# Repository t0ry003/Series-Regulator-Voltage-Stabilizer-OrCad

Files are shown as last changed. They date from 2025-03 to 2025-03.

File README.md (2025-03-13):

# Series Regulator Voltage Stabilizer (ERS)

## Overview
This project is a **Series Regulator Voltage Stabilizer (ERS)** designed to maintain a stable output voltage despite variations in input voltage and load conditions. The system leverages **error amplifiers, negative feedback loops, and protective circuits** to ensure high precision, efficiency, and reliability.

Developed as part of an academic project at the **Polytechnic University of Bucharest - Faculty of Electronics, Telecommunications, and Information Technology**, this stabilizer serves as a practical implementation of **linear voltage regulation**.

## Features
- **Precise Voltage Regulation**: Maintains a stable output voltage using an operational amplifier-based error correction system.
- **Negative Feedback Control**: Ensures accuracy by continuously comparing output voltage with a reference voltage.
- **Thermal Protection**: Automatic shutdown in case of overheating to prevent component damage.
- **Current Limiting**: Prevents excessive current draw, protecting the circuit and connected devices.
- **High Efficiency**: Optimized component selection to minimize power dissipation and improve thermal performance.

## System Design
The stabilizer consists of the following key elements:
1. **Error Amplifier**: Uses an operational amplifier in a non-inverting configuration to compare the output voltage with a reference.
2. **Voltage Reference Generator**: A Zener diode-based system provides a stable reference voltage.
3. **Series Regulating Element (ERS)**: Implements a **Darlington transistor configuration** to control the output voltage.
4. **Protection Mechanisms**:
   - **Overcurrent Protection**: Detects excessive load currents and limits output.
   - **Overtemperature Protection**: Monitors and prevents overheating of key components.

## Schematic Diagram
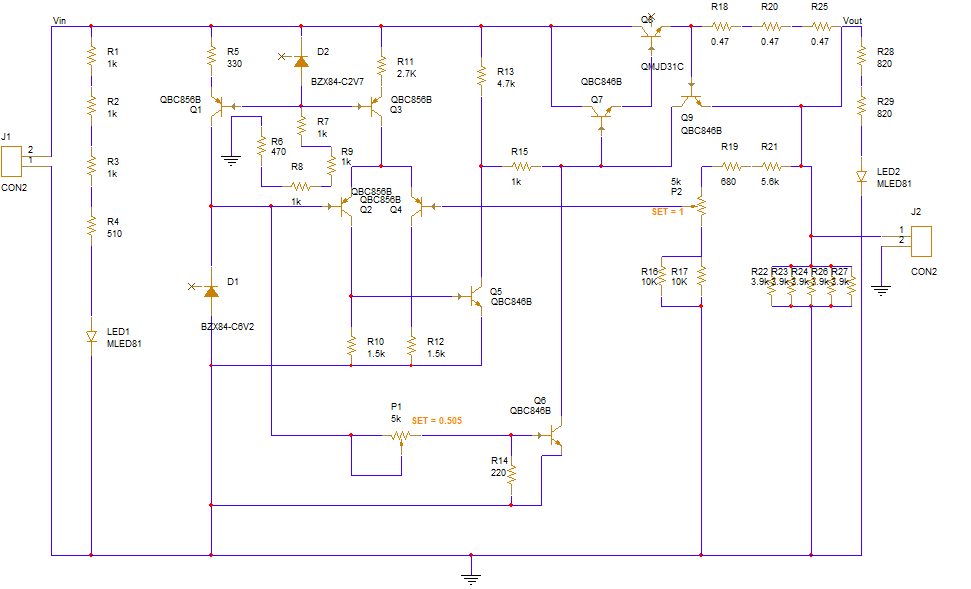
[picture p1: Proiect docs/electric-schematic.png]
Schematic Design


## PCB Design
This project includes a **fully designed PCB layout**, which can be fabricated for practical testing and implementation.
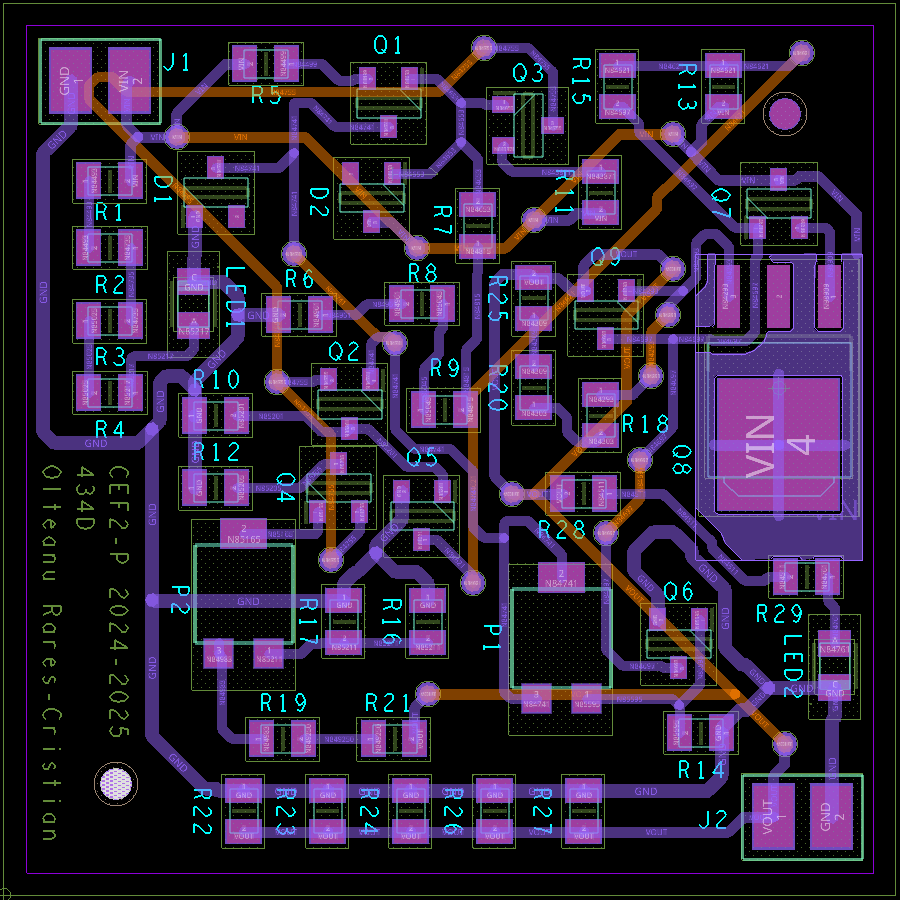
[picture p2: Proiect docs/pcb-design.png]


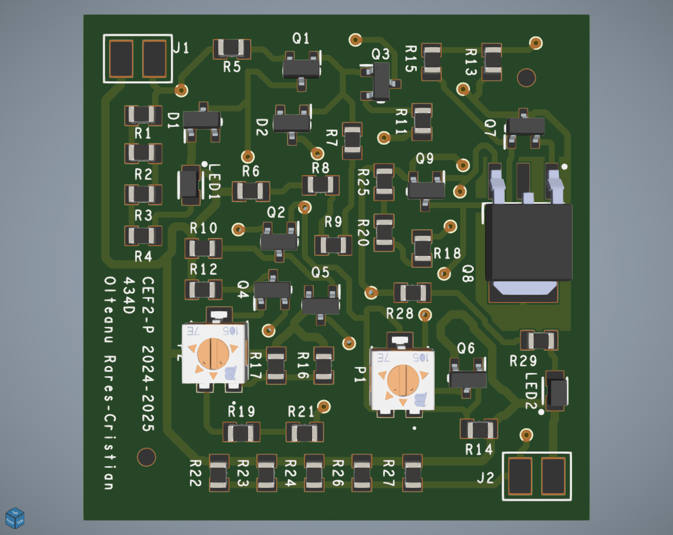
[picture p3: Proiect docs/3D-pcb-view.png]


## Simulations & Testing
Multiple simulations have been conducted to verify:
- **Output voltage stability across different input voltages (36V-40V)**
- **Response to load variations**
- **Thermal response and efficiency**
- **Gain characteristics of the error amplifier**

## How to Use
1. **Power Input**: Connect a **36V-40V DC** power source to the input terminals.
2. **Adjust Output Voltage**: Fine-tune using the onboard potentiometer (adjustable from **10V to 20V**).
3. **Monitor Performance**: Use an oscilloscope or multimeter to verify the output voltage and ensure stable operation.
4. **Safety Measures**: Ensure adequate heat dissipation and do not exceed the rated current limits.

## Bill of Materials (BOM)
| Qty | Ref | Part Number |
|-----|-----|---|
| 1 | D1  | BZX84-C6V2 |
| 1 | D2  | BZX84-C2V7 |
| 2 | J1, J2 | CON2 |
| 2 | LED1, LED2 | MLED81 |
| 2 | P1, P2 | 5k |
| 4 | Q1, Q2, Q3, Q4 | QBC856B |
| 4 | Q5, Q6, Q7, Q9 | QBC846B |
| 1 | Q8  | QMJD31C |
| 7 | R1, R2, R3, R7, R8, R9, R15 | 1k |
| 1 | R4  | 510 |
| 1 | R5  | 330 |
| 1 | R6  | 470 |
| 2 | R10, R12 | 1.5k |
| 1 | R11 | 2.7K |
| 1 | R13 | 4.7k |
| 1 | R14 | 220 |
| 2 | R16, R17 | 10K |
| 3 | R18, R20, R25 | 0.47 |
| 1 | R19 | 680 |
| 1 | R21 | 5.6k |
| 5 | R22, R23, R24, R26, R27 | 3.9k |
| 2 | R28, R29 | 820 |

## Applications
- **Power supply modules** requiring stable voltage regulation;
- **Embedded systems** where voltage precision is crucial;

## License
This project is open-source and can be used or modified under the **MIT License**.

## Contact & Credits
Developed by: **Olteanu Rareș Cristian**  
Institution: **Polytechnic University of Bucharest**  
Supervisor: **Drăghici Florin**

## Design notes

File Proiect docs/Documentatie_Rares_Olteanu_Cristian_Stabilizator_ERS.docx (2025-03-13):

# Proiect Dispozitive și Circuite Electronice

Olteanu Rareș Cristian

Grupa: 434D

Stabilizator de tensiune cu element regulator serie

Universitatea Politehnica din Bucureşti - Facultatea de Electronică şi Telecomunicaţii

Prof. Coordonator: Drăghici Florin

# 1. Stabilizatoarele de tensiune cu element de reglaj serie (ERS)

Stabilizatoarele de tensiune cu element de reglaj serie, care utilizează amplificatoare de eroare, sunt sisteme complexe, proiectate pentru a menține o tensiune constantă la ieșire în ciuda variațiilor de sarcină sau tensiune de intrare. Aceste stabilizatoare funcționează conform principiului reacției negative și sunt frecvent utilizate datorită preciziei și fiabilității lor.

## 1.1. Configurația generală a stabilizatoarelor cu amplificator operațional

Aceste stabilizatoare folosesc amplificatoare operaționale (AO) ca amplificatoare de eroare în configurație neinversoare. În această configurație avem:

1. Intrarea neinversoare primește o tensiune de referință (denumită Vref), generată de obicei de un stabilizator parametric, cum ar fi unul cu diodă Zener.

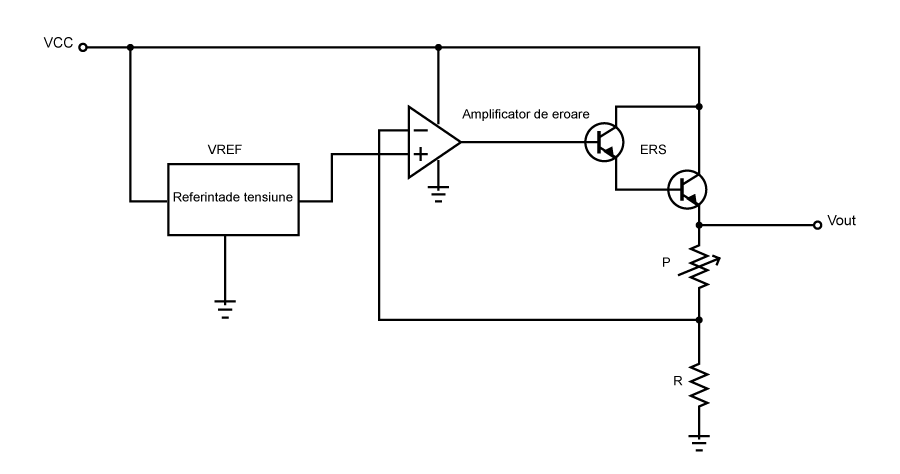
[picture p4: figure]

2. Intrarea inversoare primește o fracțiune din tensiunea de ieșire, preluată printr-un divizor de tensiune. Divizorul este format din rezistențe care ajustează nivelul semnalului proporțional cu tensiunea de ieșire.

(Fig. 1) Schema bloc a stabilizatorului de tensiune cu ERS

## 1.2. Funcționarea amplificatorului operațional

Amplificatorul operațional are un factor de amplificare foarte mare în buclă deschisă. Acest lucru determină ca diferența de potențial între intrările inversoare și neinversoare să fie extrem de mică în timpul funcționării normale. Prin urmare, orice modificare a tensiunii de ieșire care creează o diferență între aceste două intrări va genera o tensiune diferențială la ieșirea AO. Această tensiune va fi folosită pentru a corecta variația prin comanda elementului de reglaj serie, restabilind echilibrul.

## 1.3. Principiul funcționării

Stabilizatoarele liniare de tensiune continuă (SLTC) se bazează pe:

- Conexiunea cu reacție negativă, care monitorizează și ajustează continuu tensiunea de ieșire (P – potențiometrul si R – rezistenta, Fig. 1)
- Comparația între tensiunea de ieșire și tensiunea de referință, realizată de amplificatorul de eroare.

## 1.4. Indicatori de performanță ai stabilizatoarelor liniare

Calitatea unui stabilizator este determinată de mai mulți parametri esențiali:

1. Coeficientul de stabilizare (S0) - reprezintă capacitatea stabilizatorului de a menține tensiunea constantă în fața variațiilor de intrare. Valori mai mari indică o performanță superioară.
2. Rezistența de ieșire (R0) - influențează cât de mult scade tensiunea la ieșire pe măsură ce crește curentul de sarcină. Rezistența scăzută este dorită pentru o stabilitate mai bună.
3. Coeficientul de temperatură (KT) - exprimă sensibilitatea stabilizatorului la variațiile de temperatură. O valoare mică asigură o performanță constantă în condiții de mediu diferite.

## 1.5. Protecții integrate în stabilizatoare

Pentru a preveni deteriorarea circuitului în condiții de suprasarcină sau scurtcircuit, majoritatea stabilizatoarelor liniare moderne includ:

- Circuite de limitare a curentului de ieșire, care previn suprasolicitarea regulatorului serie. Această limitare poate fi:
1. Simplă, protejând doar împotriva curentului excesiv.
2. Cu întoarcerea curentului, unde, în cazul unui scurtcircuit, se reduce și puterea disipată de regulator.

## 1.6. Structura amplificatorului de eroare

S-a utilizat o configurație de amplificator operațional neinversor, în care factorul de amplificare în tensiune (Av) este determinat de relația matematică:

A_ν =1+(R_2)/(R_1)

Pentru implementarea amplificatorului de eroare, s-a adoptat o arhitectură clasică de amplificator operațional în clasa A, care este structurată în două secțiuni principale:

1. Secțiunea de intrare și semnal mic, responsabilă pentru adaptarea impedanțelor și procesarea semnalului de mică amplitudine.
2. Secțiunea de amplificare în tensiune, care realizează o amplificare semnificativă a semnalului.

Această divizare permite utilizarea etajelor specializate fie pentru amplificare în curent, fie pentru amplificare în tensiune, optimizând astfel performanța generală a circuitului.

### 1.6.1. Etajele amplificatorului

#### a) Etajul de intrare

Etajul de intrare este configurat ca amplificator diferențial, având rolul principal de a asigura adaptarea impedanței între sursa de semnal (impedanță mare) și etajele ulterioare (impedanță mică). Acesta funcționează conform principiului de transconductanță, transformând semnalul de intrare de tip tensiune într-un semnal de tip curent.

#### b) Etajul de amplificare în tensiune

Al doilea etaj, dedicat amplificării semnalului, este de tip trans impedanță și transformă curentul provenit de la etajul de intrare într-un semnal de tensiune de amplitudine mare. Amplificarea în tensiune a acestui etaj este extrem de mare în regim de buclă deschisă. Pentru a asigura o funcționare stabilă și o amplificare utilă, se implementează obligatoriu o buclă de reacție negativă, care reduce amplificarea totală la o valoare controlată.

### 1.6.2. Caracteristici funcționale ale etajelor amplificatorului

Etajele amplificatorului sunt conectate în cascadă, ceea ce determină înmulțirea factorilor de amplificare individuali. Cu toate acestea, etajul pilot contribuie majoritar la amplificarea totală în tensiune a amplificatorului.

## 1.7. Componente adiționale

Pe lângă etajele de amplificare, circuitul este completat de următoarele componente:

- Circuite de protecție, care asigură fiabilitatea în condiții de funcționare anormală (suprasarcină, temperatură, etc.).
- Generator de tensiune de referință, care furnizează un semnal stabil utilizat ca punct de comparație pentru amplificatorul de eroare.
- Rețea de reacție, utilizată pentru controlul precis al tensiunii de ieșire prin ajustarea amplificării și stabilității circuitului.

Această arhitectură permite obținerea unei amplificări eficiente, cu performanțe stabile și adaptabile diverselor aplicații.

# 2. Funcționarea schemei

(Fig. 2) Schema circuit stabilizator de tensiune cu ERS

(Fig. 3) Tensiunea de referința si amplificatorul de eroare diferențial

Proiectul a fost realizat pentru N = 20

## 2.1. Referința de tensiune

Referința de tensiune este generată cu ajutorul unei diodă Zener (D2), alimentată printr-un curent constant asigurat de tranzistorul Q1 și rezistența R2. Alegerea diodei Zener se face astfel încât tensiunea sa nominală (VZ) să fie mai mică decât tensiunea minimă ce trebuie obținută la ieșire (Vmin). În acest caz, s-a optat pentru o diodă Zener cu VZ = 6.2V. (Fig. 3)

Curentul constant prin dioda Zener D2 este generat de tranzistorul Q1, care formează o sursă de curent constant. Aceasta asigură o tensiune de referință stabilă pentru funcționarea optimă a schemei.

## 2.2. Etajul diferențial

Elementul central al schemei este amplificatorul diferențial, realizat cu tranzistoarele Q3 și Q4. Acesta este alimentat printr-o sursă de curent constant, formată din tranzistorul Q2 și rezistența R4. (Fig. 3)

Rolul acestui etaj este de a realiza atât amplificarea în tensiune, cât și amplificarea în curent. Pentru îndeplinirea acestor sarcini se folosesc etaje specializate:

- Etajul de intrare facilitează adaptarea între sursa de semnal și amplificator.
- În plus, contribuie la eliminarea fluctuațiilor provenite de la sursa de alimentare, având un impact direct asupra raportului semnal-zgomot.

## 2.3. Stabilizarea tensiunii

Pentru a îmbunătăți stabilitatea circuitului, o diodă D1 este utilizată pentru a menține tensiunea constantă pe sursele de curent constant. Aceasta fixează tensiunea pe rezistențele R2 și R4, ceea ce contribuie la stabilizarea generală a circuitului. (Fig. 3)

Astfel, integrarea diodei D1 reduce variațiile nedorite, îmbunătățind performanțele sursei de alimentare și menținând parametrii tensiunii de ieșire în limite stricte.

La pornire, joncțiunea bază-emitor (BE) a tranzistorului Q1 intră în conducție prin intermediul rezistorului R1. Curentul furnizat de această sursă poate fi calculat utilizând formula:

I_(C_1) =(v_z -v_(BE))/(R_2)

I_(C_1) =6mA

Curentul prin etajul diferențial este stabilit de rezistența R4, având la borne o tensiune de aproximativ:

v_z -v_(BE)

Astfel, curentul IC2 este calculat ca:

I_(C2) =0.8mA

Cum curentul colector al tranzistoarelor Q3 și Q4 este împărțit egal:

Ic_3 +I_(C4) =(Ic_2)/2 → Ic_3 =I_(C4) =0.4mA

Rezistențele R5 și R6 furnizează curentul de polarizare pentru etajul următor. Rezistorul R5 este dimensionat astfel încât să asigure o cădere de tensiune minimă de 0.6V, necesară pentru a aduce în conducție tranzistorul Q5.

### 2.3.1. Componentele utilizate

- Etajul diferențial este realizat cu tranzistoare bipolare PNP de tipul BC856.
- Etajul de emitor comun utilizează un tranzistor NPN de tipul BC846.

Aceste tranzistoare sunt adecvate, deoarece:

- Tensiunea de alimentare a circuitului este de 40V.
- Curentul colector pentru fiecare tranzistor diferențial Q3 și Q4 este limitat la 0.4mA.

### 2.3.2. Etajul amplificator în tensiune

Etajul de amplificare în tensiune este format dintr-un singur tranzistor bipolar Q5, configurat ca emitor comun. Sarcina acestui etaj este rezistorul R7.

Curentul prin R7 poate fi determinat cunoscând că tensiunea la bornele acestuia este aproape întotdeauna egală cu:

V_(CC) - V_(OUT) +2V_(BE)

Această configurație asigură funcționarea stabilă și precisă a circuitului.

Curentul IC5 este egal cu curentul IR7, iar relația acestuia poate fi exprimată astfel:

I_(C5) =I_(R7) =(V_(CC) -V_(OUT) +2V_(BE))/(R_7)

Amplificarea în tensiune a etajului emitor comun depinde de rezistența internă de emitor și de rezistența văzută în colector (adică a sursei de curent). Aceasta se poate calcula folosind formula:

A_(V5) =(R_7)/(R_(E5))

Unde R_(E5) =(V_T)/(I_C) , rezulta R_(E5) =(25mV)/(4mA)≅6Ω

R_7 =4.7kΩ , rezulta A_(V5) ≅780

(Fig. 4) Elementul regulator serie

## 2.4. Elementul regulator serie (ERS)

Elementul regulator serie este realizat pe baza unei conexiuni de colector comun. Acest tip de etaj oferă doar amplificare în curent și este numit și etaj final, deoarece asigură adaptarea către impedanța sarcinii. Scopul acestui etaj este să amplifice în curent, menținând în același timp o amplificare unitară în tensiune.

Pentru a asigura condiția de amplificare unitară în tensiune, vom utiliza o conexiune de tip colector comun realizată cu două tranzistoare bipolare în configurație Darlington (Q6 si Q7). Această configurație oferă cea mai mare amplificare în curent posibilă. Factorii de amplificare ai celor două tranzistoare se înmulțesc, rezultând o amplificare în curent de ordinul 10⁴. (Fig. 4)

Tranzistorul final este Q7, care conduce cea mai mare parte a curentului. Din acest motiv, a fost ales modelul MJD31, deoarece poate suporta curenți de până la 3A și poate disipa o putere mai mare decât alte modele de tranzistoare (pana la 25W, comparat cu altele care suporta pana la 250mW).

(Fig. 5) Circuitul de protecție la supracurent

## 2.5. Circuitul de protecție la supracurent

Circuitul de protecție la supracurent Q9 + R10 + R11 + R12 este realizat cu un tranzistor bipolar NPN. Tensiunea VBE a tranzistorului este generată de căderea de tensiune pe aceste rezistoare. Astfel, la curenți mari (>0.5A), tranzistorul Q9 va intra în conducție și va limita curentul de bază al regulatorului serie.

Pentru a obține o valoare precisă de 1.4 Ω, au fost utilizate trei rezistoare în serie.

Dimensionarea rezistorului se face conform relației:

R=(V_(BE))/(I_(OMAX))

R = R10 + R11 + R12

Astfel, pentru un curent maxim de 0.5 A, rezultă o valoare de aproximativ 1.4 Ω pentru R.

(Fig. 6) Circuitul de protecție la temperatură

## 2.6. Circuitul de protecție la temperatură

Circuitul de protecție la temperatură este realizat cu Q8 și un divizor rezistiv format din P2 și R8.

Tensiunea bază-emitor pentru Q8 este stabilită de divizor la un nivel care împiedică intrarea în conducție a tranzistorului Q8 (aproximativ 400 mV). Totuși, la temperaturi ridicate, datorită coeficientului termic negativ al joncțiunilor din siliciu (−2 mV/°C), potențialul stabilit de divizor devine suficient de mare pentru ca Q8 să intre în conducție.

Astfel, la temperaturi de peste 120°C, se limitează curentul de bază al regulatorului serie, iar tensiunea de la ieșire scade către 0.

Potențialul VBE este stabilit la aproximativ 400 mV conform raportului dintre P2 și R8, după relația:

V_(BE8) =V_(ref) ×(P_2)/(R_8 +P_2) , unde V_(ref) =6.2V

Din potențiometrul P2 se reglează cu precizie valoarea temperaturii la care acționează protecția. In acest caz a fost reglat la 0.505 (2,525kΩ)

(Fig. 7) Rețeaua de reacție negativă

## 2.7. Rețeaua de reacție negativă

Rețeaua de reacție negativă este formata din potențiometrul P1 si doua grupuri de rezistente: R14, R15 si R16, R17 . Acestea realizează un divizor de tensiune variabil din potențiometru care are ca scop reglarea tensiunii de ieșire.

Știm că V_(out min) =10V, V_(out max) =20V, V_(ref) =6.2V

R=6.2/10=0.62kΩ

V_(ref) =V_(out min) ×(P_1 +R_16 ∥R_17)/(P_1 +R_16 ∥R_17 +R_14 +R_15)=10V×10/(10+6.28)kΩ=6.14V

R=6.2/20=0.31kΩ

V_(ref) =V_(out min) ×(R_16 ∥R_17)/(P_1 +R_16 ∥R_17 +R_14 +R_15)=10V×5/(10+6.28)kΩ=6.14V

Din aceste relații, am ales valorile:

R_14 =0.6kΩ, R_15 =5.6kΩ, R_16 =R_17 =10kΩ (R_16 ∥R_17 =5kΩ), P_1 =5kΩ

# 3. Punct static de funcționare (simulari)

(Fig. 8) Punct static de funcționare – afișare tensiuni

(Fig. 9) Punct static de funcționare – afișare curenți

(Fig. 10) Punct static de funcționare – afișare puteri disipate

Se poate observa alegerea corecta a componentelor electrice si folosirea lor corespunzătoare. Au fost respectate toate cerințele impuse de producător, ba chiar la majoritatea a fost lăsata o marjă pentru siguranță.

# 4. Simulări funcționalitate

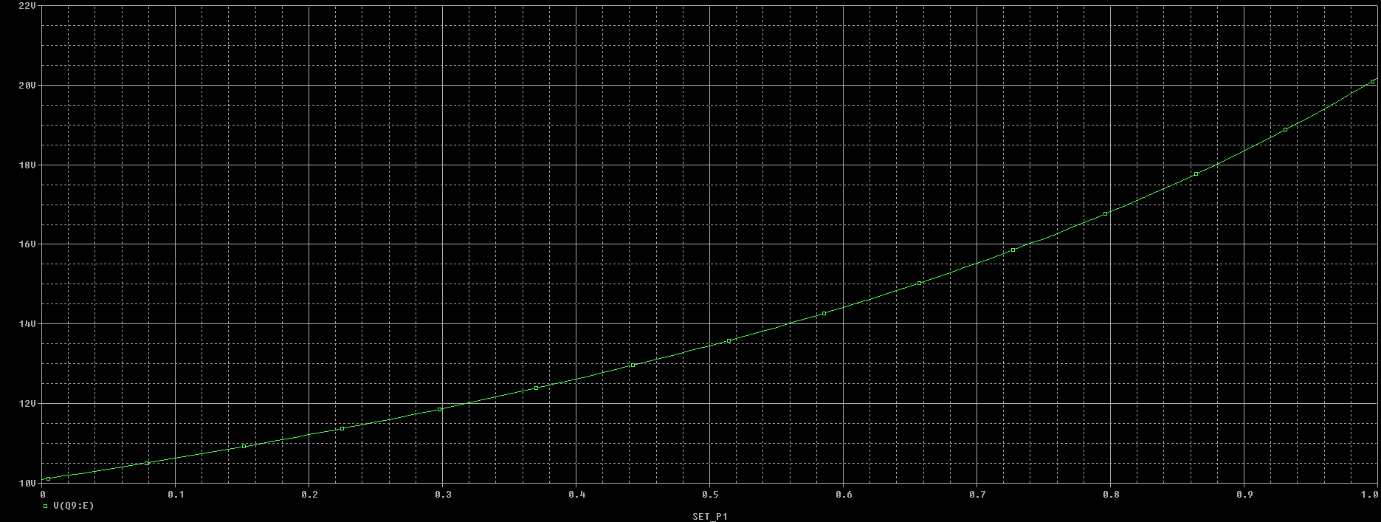
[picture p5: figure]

## 4.1. Reglajul tensiunii de ieșire din potențiometrul P1

(Fig. 11) Graficul variației tensiunii de ieșire din P1

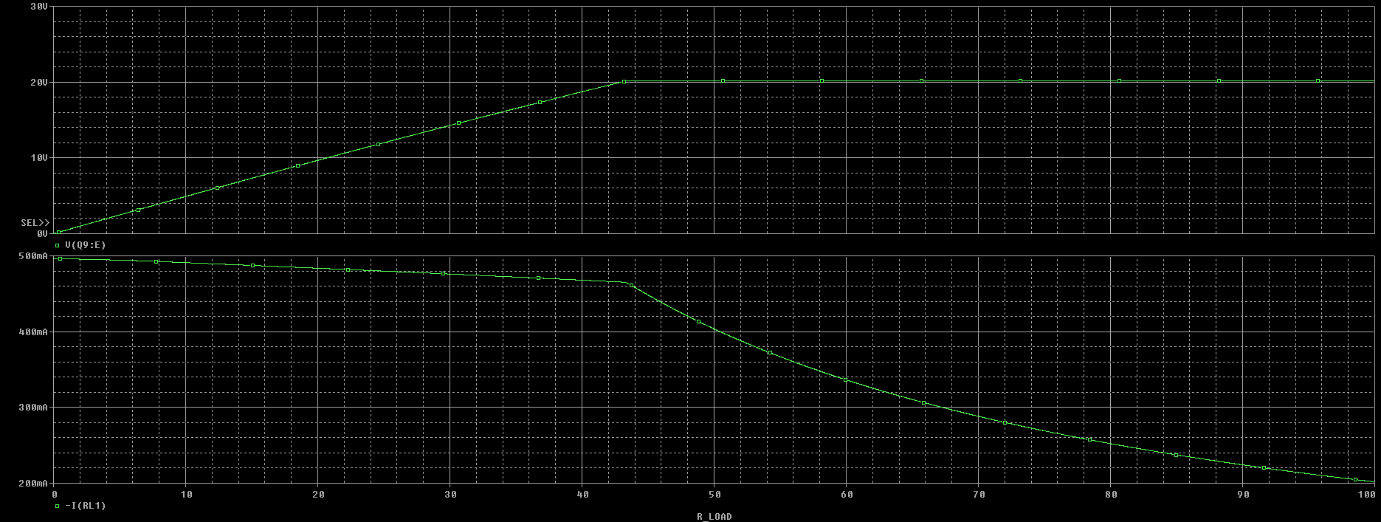
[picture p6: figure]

## 4.2. Variația rezistenței de sarcina RLOAD

(Fig. 12) Graficul variației rezistentei de sarcina, protecția la supra-curent

## 4.3. Variația tensiunii de intrare

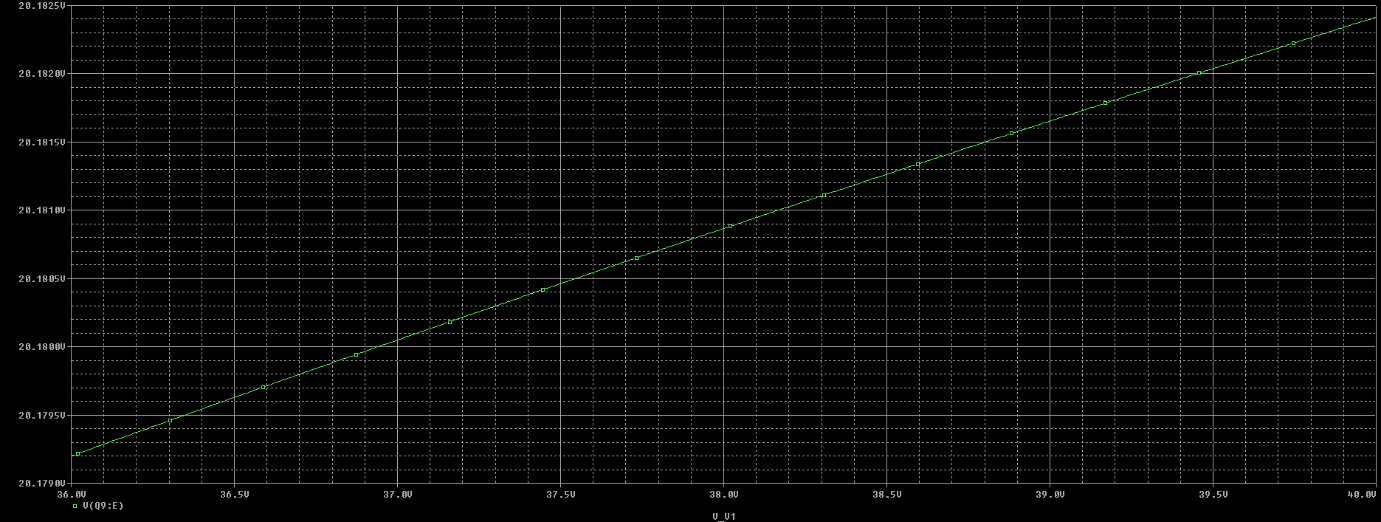
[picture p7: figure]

(Fig. 13) Graficul variației tensiunii de intrare intre 36÷40V

## 4.4. Variația temperaturii, protecția de temperatura

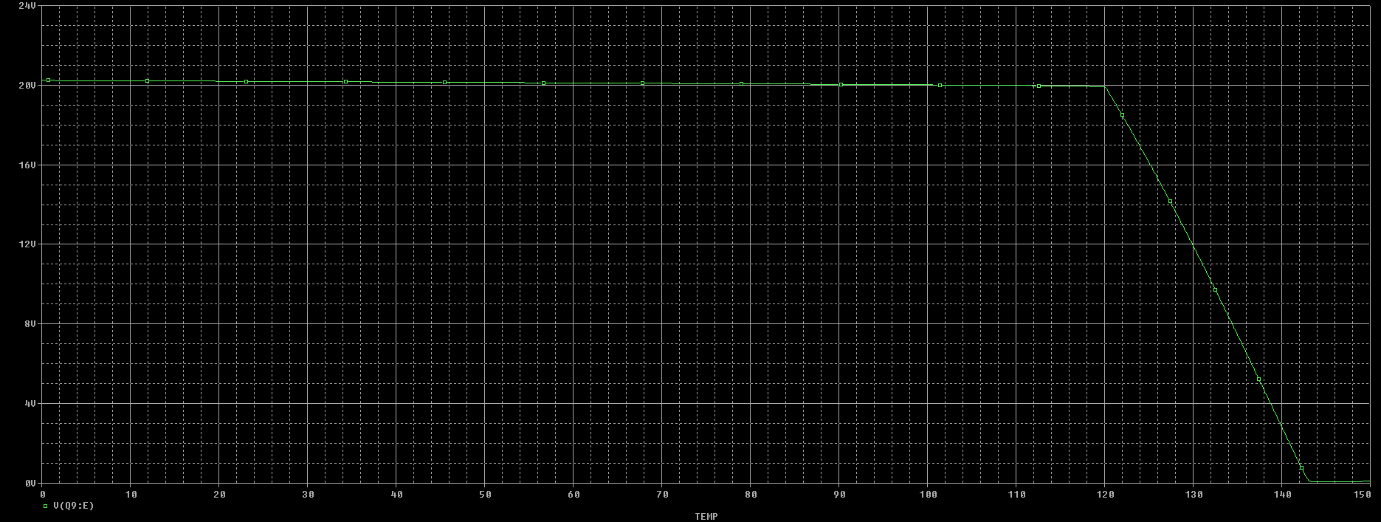
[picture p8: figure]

(Fig. 14) Graficul variației temperaturii, simulare pentru protecția de temperatura

Deriva termica este aproximativ 1.5mV/°C

## 4.5. Simularea amplificării in buclă deschisă

(Fig. 15) Graficul amplificării de tensiune in buclă deschisă

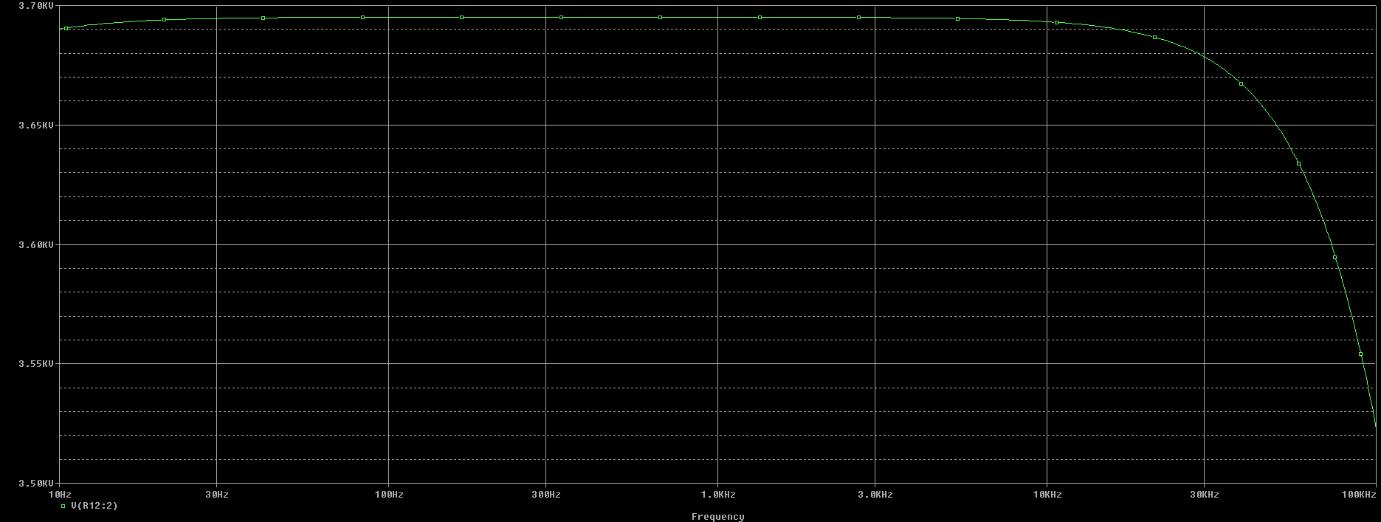
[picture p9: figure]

Amplificatorul de eroare are AV > 3690

# 5. Transfer Capture-PCB

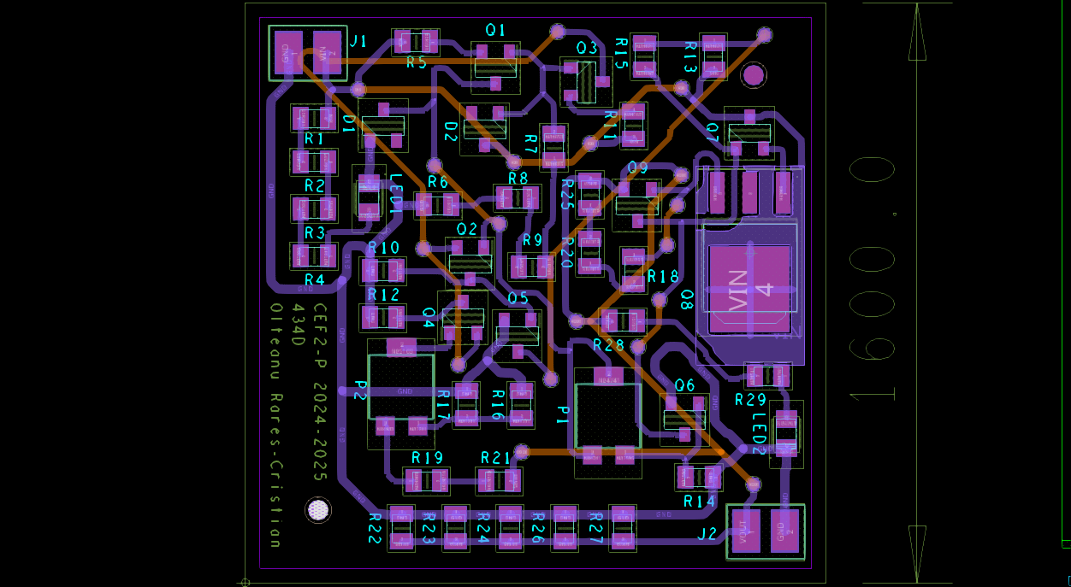
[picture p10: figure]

(Fig. 16) PCB Design

Cuprins

Rareş-Cristian OLTEANU Stabilizator de tensiune cu ERS

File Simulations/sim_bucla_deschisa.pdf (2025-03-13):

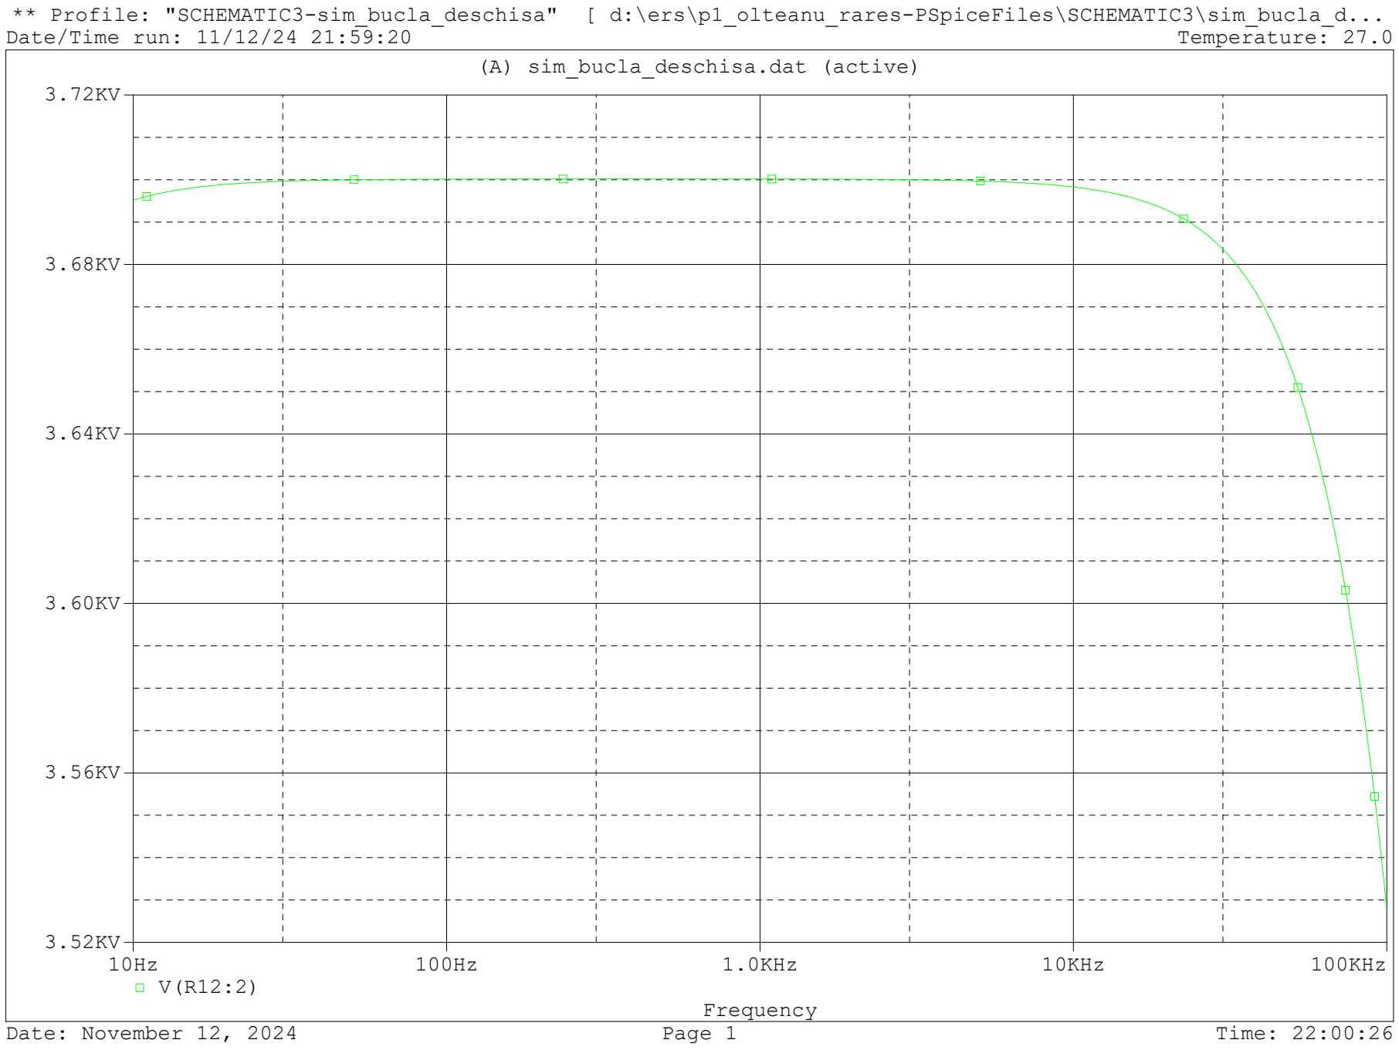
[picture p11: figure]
Date/Time run: 11/12/24 21:59:20; ** Profile: "SCHEMATIC3-sim_bucla_deschisa" [ d:\ers\p1_olteanu_rares-PSpiceFiles\SCHEMATIC3\sim_bucla_d... Temperature: 27.0; Date: November 12, 2024; Page 1; Time: 22:00:26; (A) sim_bucla_deschisa.dat (active); Frequency; 1.0KHz; 10KHz; 100KHz

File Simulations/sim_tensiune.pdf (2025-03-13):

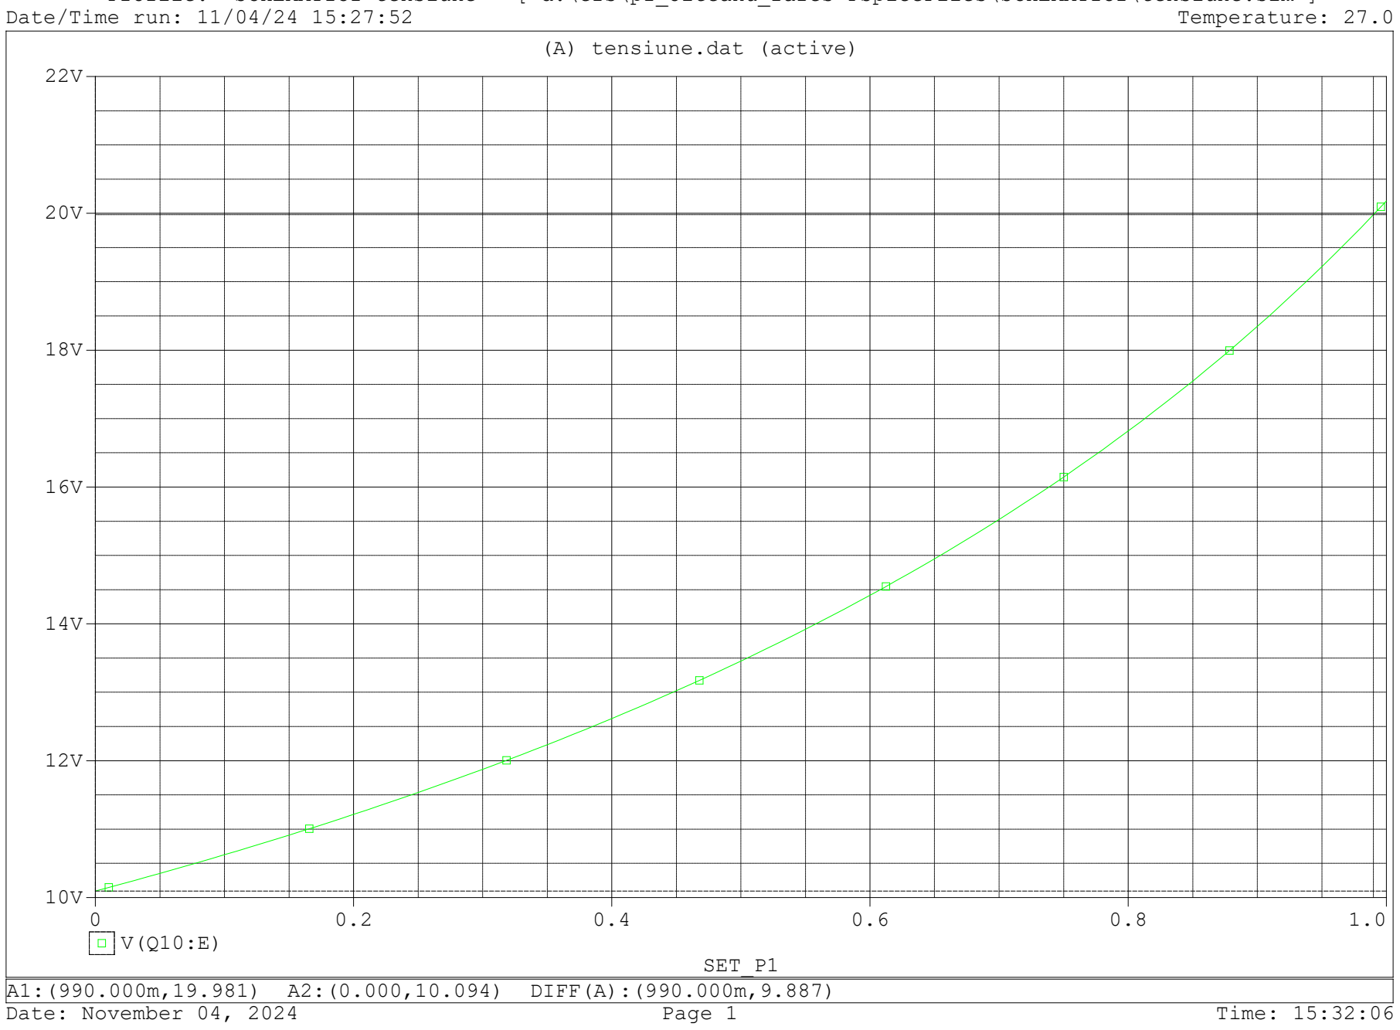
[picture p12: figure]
A1:(990.000m,19.981) A2:(0.000,10.094) DIFF(A):(990.000m,9.887); Date/Time run: 11/04/24 15:27:52; Temperature: 27.0; Date: November 04, 2024; Page 1; Time: 15:32:06; (A) tensiune.dat (active); SET_P1

** Profile: "SCHEMATIC1-tensiune" [ d:\ers\p1_olteanu_rares-PSpiceFiles\SCHEMATIC1\tensiune.sim ]

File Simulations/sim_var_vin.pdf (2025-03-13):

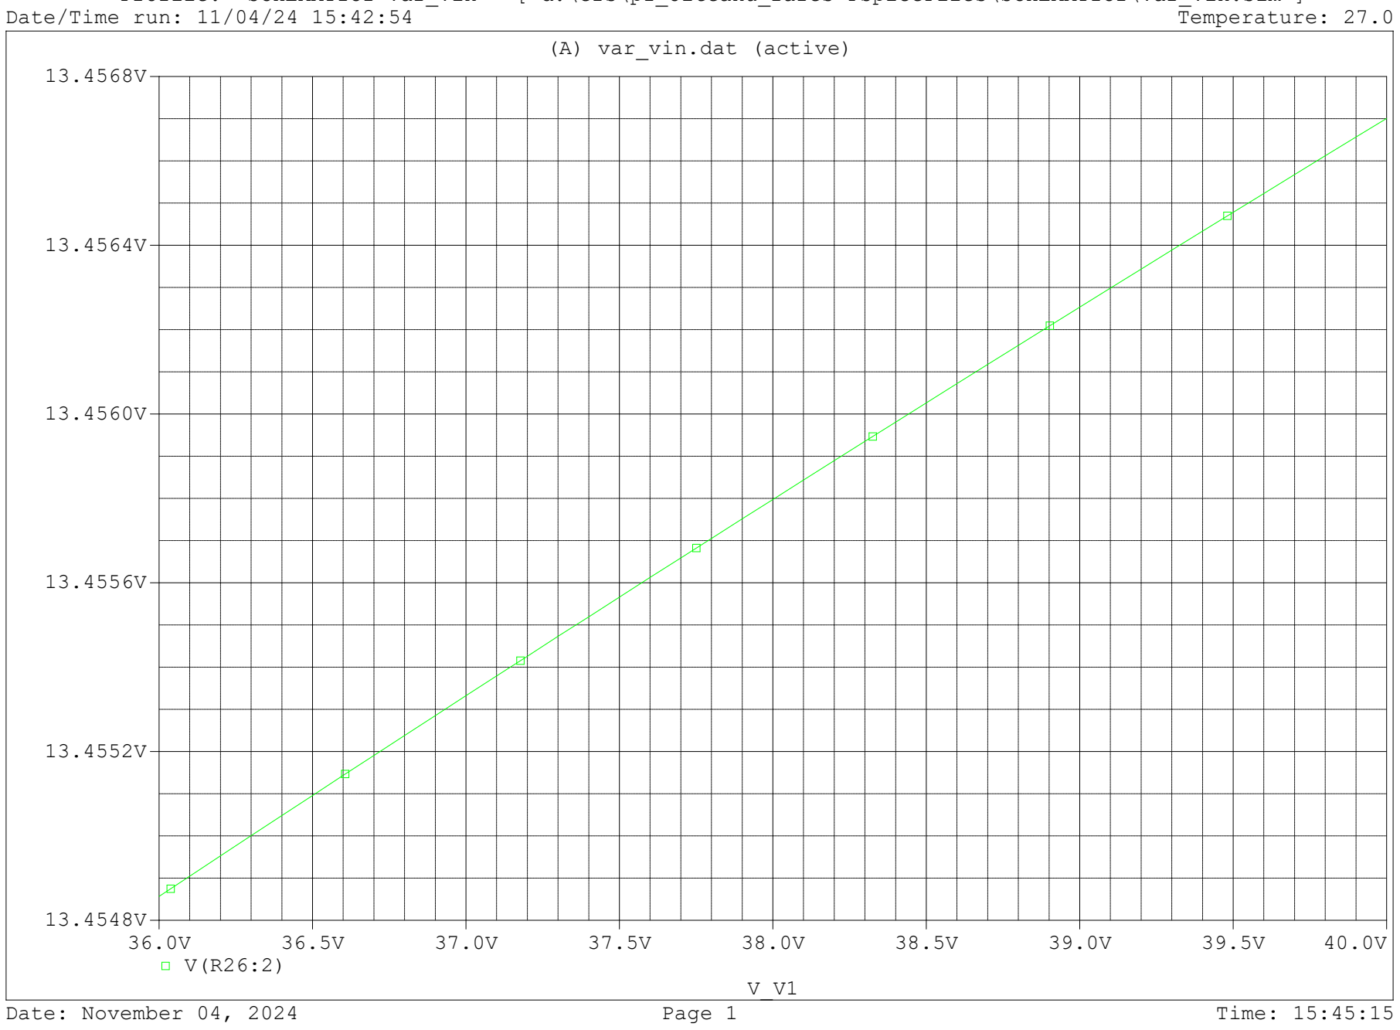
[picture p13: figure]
Date/Time run: 11/04/24 15:42:54; Temperature: 27.0; Date: November 04, 2024; Page 1; Time: 15:45:15; (A) var_vin.dat (active)

** Profile: "SCHEMATIC1-var_vin" [ d:\ers\p1_olteanu_rares-PSpiceFiles\SCHEMATIC1\var_vin.sim ]

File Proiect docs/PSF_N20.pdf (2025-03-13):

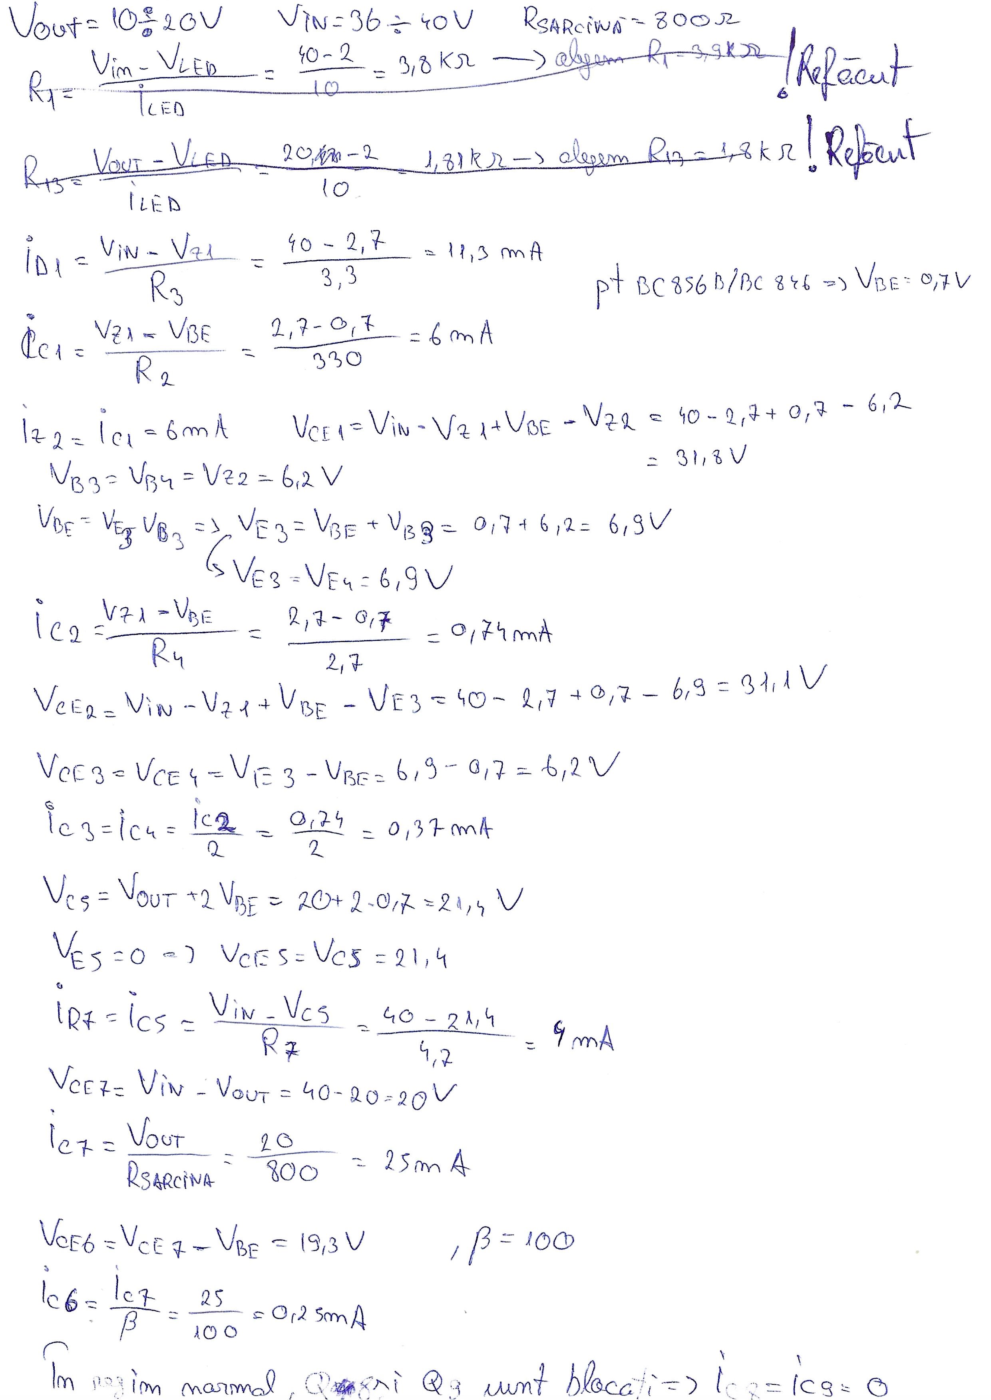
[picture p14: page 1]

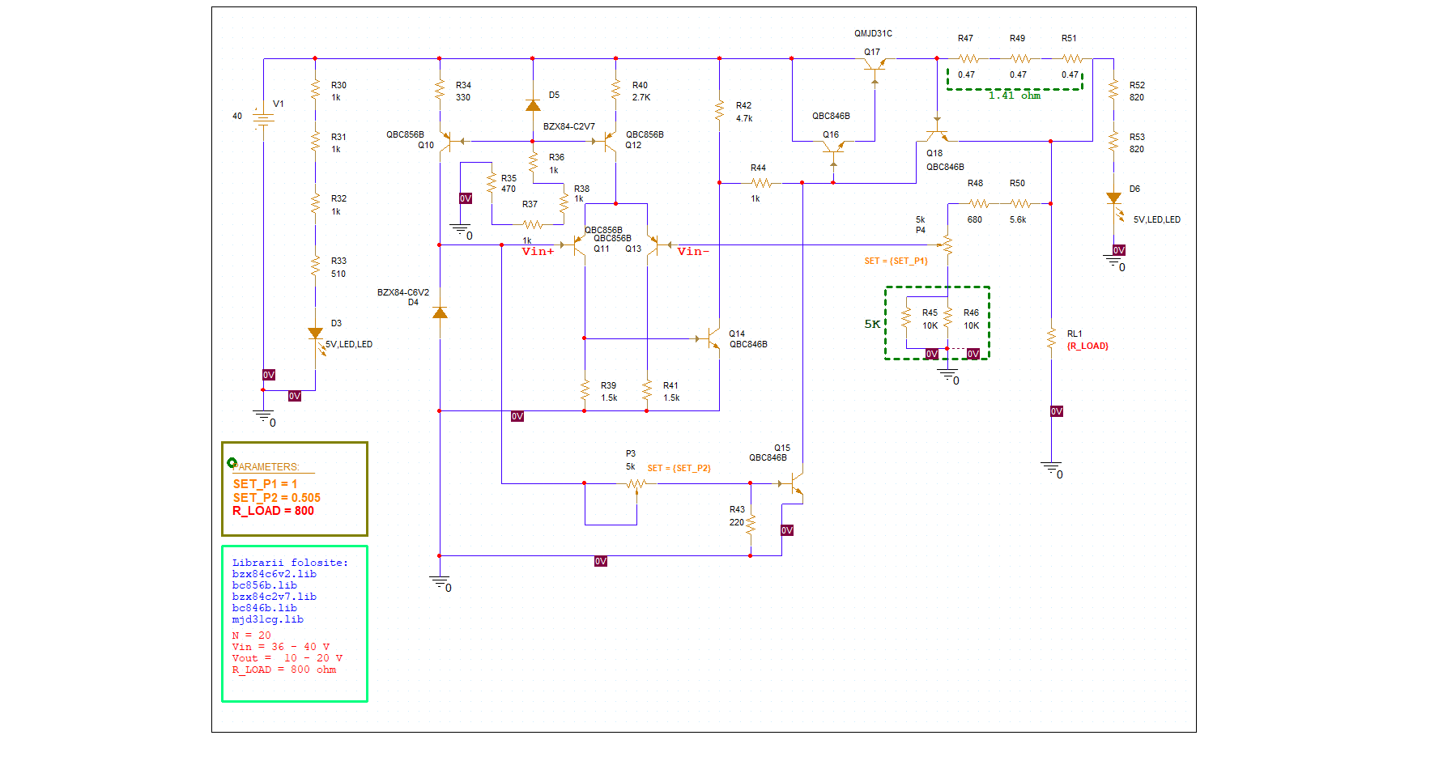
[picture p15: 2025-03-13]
Schematics/P1_OLTEANU_RARES.png

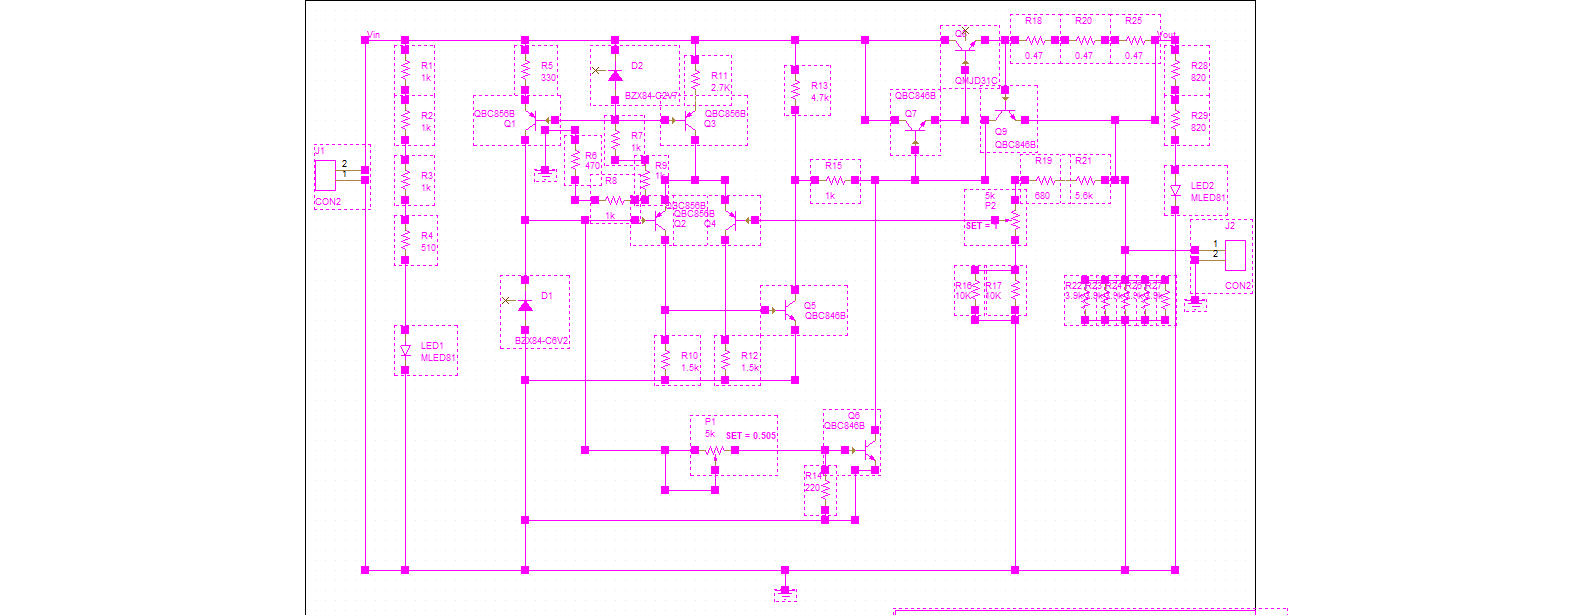
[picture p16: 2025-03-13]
Schematics/1/P1_OLTEANU_RARES.png

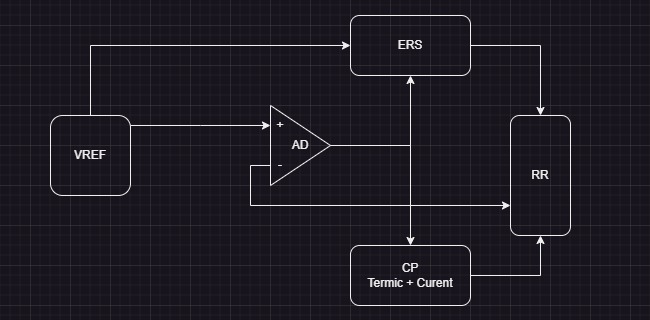
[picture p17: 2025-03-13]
schema_bloc.jpg

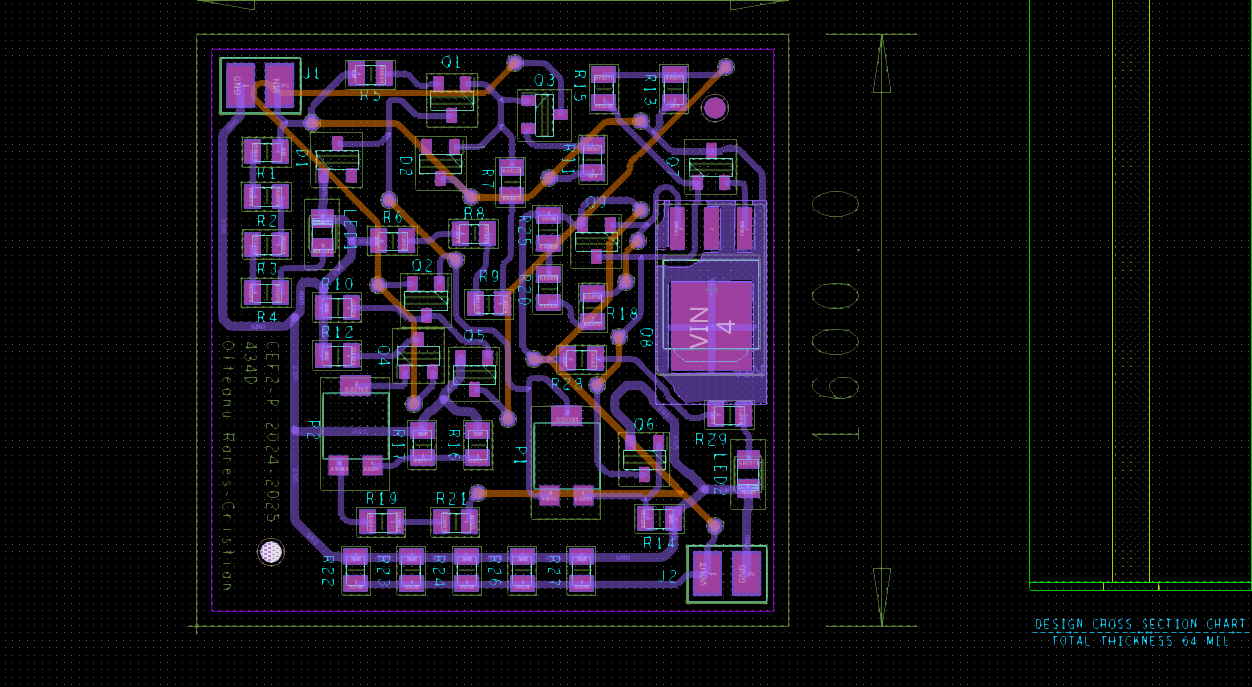
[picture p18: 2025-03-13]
Layout/p1_olteanu_rares.jpg

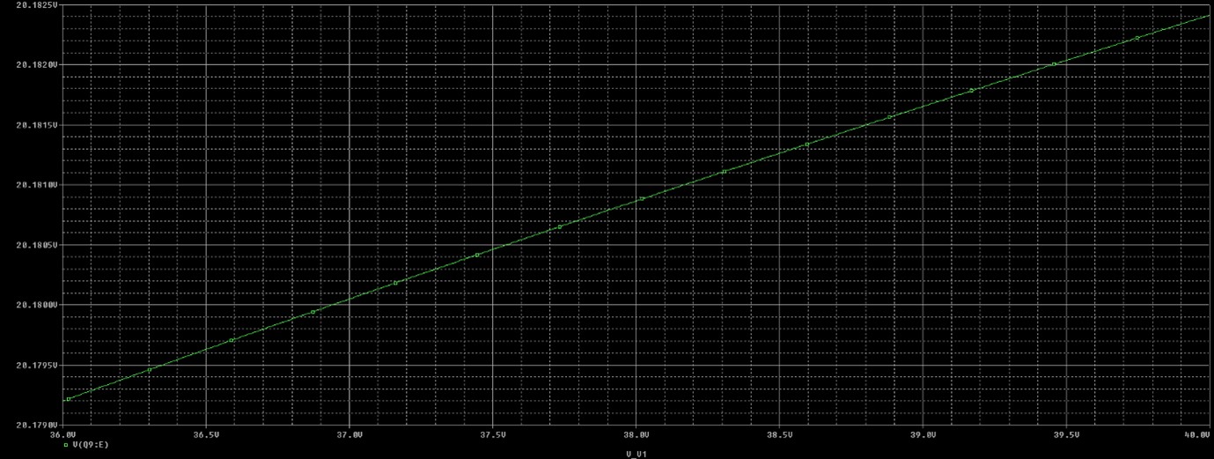
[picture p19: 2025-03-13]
Simulations/sim_var_vin.jpg

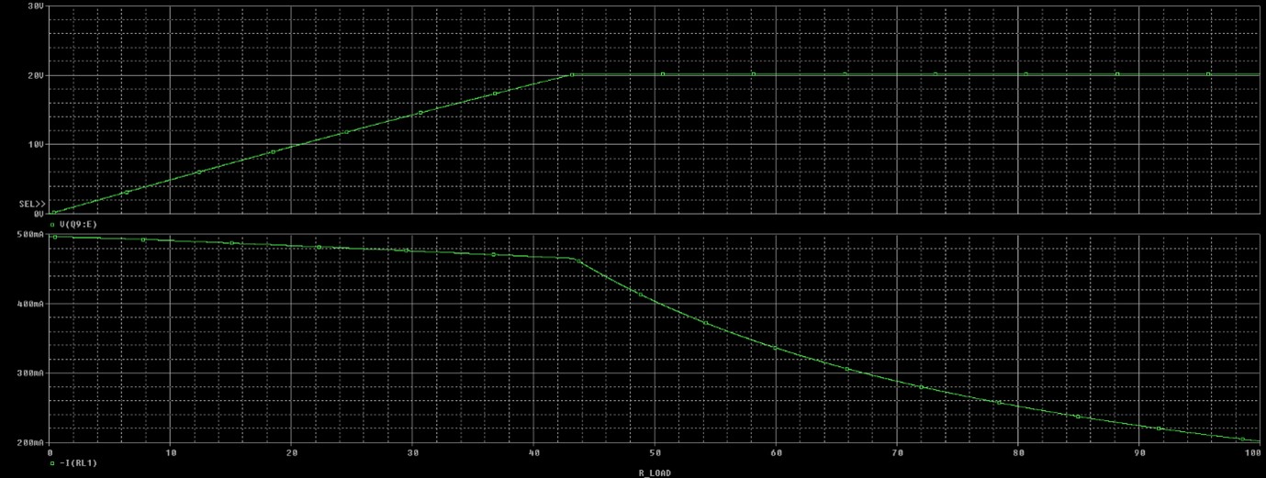
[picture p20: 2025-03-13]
Simulations/sim_sarcina_curent.jpg

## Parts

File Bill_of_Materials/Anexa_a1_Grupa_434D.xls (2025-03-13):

Anexa a1 - Grupa 434D - Tema 3 - Stabilizator de tensiune cu ERS
Nr. Crt. | Nume | Catalog | Cod distrib | Nume prod | Prod | Clasă | Qty fix | Qty final | Qty min | Descriere | Distribuitor | Pret (fara TVA) referinta/buc. TME România | Pret total pe reper (fara TVA) - propus
1 | 0 ohm | (LINK) (http://www.tme.eu/ro/details/smd1206-0r/rezistente-smd-1206/royal-ohm/1206s4j0000t5e/) | 1206S4J0000T5E | 1206S4J0000T5E | SR PASSIVES | rezistor | 0 |  |  | Rezistor: thick film; SMD; 1206; 0Ω; 0,25W; ±5%; -55÷125°C | TME România | 0.03841 | 0
2 | 0.47 | (LINK) (http://www.tme.eu/ro/details/smd0805-0r47/rezistente-smd-0805/royal-ohm/0805s8j047kt5e/) | SMD0805-0R47 | 0805S8J047KT5E | ROYAL OHM | rezistor | 20 |  | 3 | Rezistor SMD, chip, 0805, 0.47Ω, ±5%, 0.125W | TME România | 0.01454 | 0.2908
3 | 1 | (LINK) (https://www.tme.eu/ro/details/smd0805-1r/rezistente-smd-0805/royal-ohm/0805s8j010jt5e/) | SMD0805-1R-5% | 0805S8J010JT5E | ROYAL OHM | rezistor | 20 |  |  | Rezistor SMD, chip, 0805, 1Ω, ±5%, 0.125W | TME România | 0.01723 | 0.3446
4 | 4.7 | (LINK) (https://www.tme.eu/ro/details/smd0805-4r7/rezistente-smd-0805/royal-ohm/0805s8j047jt5e/) | SMD0805-4R7-5% | 0805S8J047JT5E | ROYAL OHM | rezistor | 10 |  |  | Rezistor SMD, chip, 0805, 4.7Ω, ±5%, 0.125W | TME România | 0.01723 | 0.1723
5 | 10 | (LINK) (https://www.tme.eu/ro/details/smd0805-10r/rezistente-smd-0805/royal-ohm/0805s8j0100t5e/) | SMD0805-10R-5% | 0805S8J0100T5E | ROYAL OHM | rezistor | 10 |  |  | Rezistor SMD, chip, 0805, 10Ω, ±5%, 0.125W | TME România | 0.01723 | 0.1723
6 | 22 | (LINK) (https://www.tme.eu/ro/details/smd0805-22r-1%25/rezistente-smd-0805/royal-ohm/0805s8f220jt5e/) | SMD0805-22R-1% | 0805S8F220JT5E | ROYAL OHM | rezistor | 20 |  |  | Rezistor SMD, chip, 0805, 22Ω, ±1%, 0.125W | TME România | 0.02127 | 0.4254
7 | 33 | (LINK) (https://www.tme.eu/ro/details/smd0805-33r/rezistente-smd-0805/royal-ohm/0805s8j0330t5e/) | SMD0805-33R-5% | 0805S8J0330T5E | ROYAL OHM | rezistor | 20 |  |  | Rezistor SMD, chip, 0805, 33Ω, ±5%, 0.125W | TME România | 0.01723 | 0.3446
8 | 51 | (LINK) (http://www.tme.eu/ro/details/rc0805jr-0751r/rezistente-smd-0805/yageo/rc0805jr-0751rl/) | SMD0805-51R-5% | 0805S8J0510T5E | ROYAL OHM | rezistor | 40 |  |  | Rezistor SMD, chip, 0805, 51Ω, ±5%, 0.125W | TME România | 0.0261 | 1.044
9 | 68 | (LINK) (http://www.tme.eu/ro/details/smd0805-68r-1%25/rezistente-smd-0805/royal-ohm/0805s8f680jt5e/) | SMD0805-68R-1% | 0805S8F680JT5E | ROYAL OHM | rezistor | 10 |  |  | Rezistor SMD, chip, 0805, 68Ω, ±1%, 0.125W | TME România | 0.04662 | 0.4662
10 | 82 | (LINK) (https://www.tme.eu/ro/details/wf08p-82r-5%25/rezistente-smd-0805/walsin/wf08p820jtl/) | SMD0805-82R-5% | WF08P820JTL | WALSIN | rezistor | 20 |  |  | Rezistor SMD, chip, 0805, 82Ω, ±5%, 0.125W | TME România | 0.0172 | 0.344
11 | 100 | (LINK) (https://www.tme.eu/ro/details/smd0805-100r/rezistente-smd-0805/royal-ohm/0805s8j0101t5e/) | SMD0805-100R-5% | 0805S8J0101T5E | ROYAL OHM | rezistor | 60 |  |  | Rezistor SMD, chip, 0805, 100Ω, ±5%, 0.125W | TME România | 0.01723 | 1.0338
12 | 150 | (LINK) (https://www.tme.eu/ro/details/smd0805-150r/rezistente-smd-0805/royal-ohm/0805s8j0151t5e/) | SMD0805-150R-5% | 0805S8F1500T5E | ROYAL OHM | rezistor | 30 |  |  | Rezistor SMD, chip, 0805, 150Ω, ±5%, 0.125W | TME România | 0.01723 | 0.5169
13 | 220 | (LINK) (http://www.tme.eu/ro/details/smd0805-220r-1%25/rezistente-smd-0805/royal-ohm/0805s8f2200t5e/) | SMD0805-220R-5% | 0805S8J0221T5E | ROYAL OHM | rezistor | 30 |  | 1 | Rezistor SMD, chip, 0805, 220Ω, ±5%, 0.125W | TME România | 0.02127 | 0.6381
14 | 330 | (LINK) (https://www.tme.eu/ro/details/smd0805-330r/rezistente-smd-0805/royal-ohm/0805s8j0331t5e/) | SMD0805-330R-5% | 0805S8J0331T5E | ROYAL OHM | rezistor | 30 |  | 1 | Rezistor SMD, chip, 0805, 330Ω, ±5%, 0.125W | TME România | 0.01723 | 0.5169
15 | 470 | (LINK) (https://www.tme.eu/ro/details/smd0805-470r/rezistente-smd-0805/royal-ohm/0805s8j0471t5e/) | SMD0805-470R-5% | 0805S8J0471T5E | ROYAL OHM | rezistor | 30 |  | 1 | Rezistor SMD, chip, 0805, 470Ω, ±5%, 0.125W | TME România | 0.01723 | 0.5169
16 | 510 | (LINK) (https://www.tme.eu/ro/details/smd0805-510r/rezistente-smd-0805/royal-ohm/0805s8j0511t5e/) | SMD0805-510R-5% | 0805S8J0511T5E | YAGEO | rezistor | 30 |  | 1 | Rezistor SMD, chip, 0805, 510Ω, ±5%, 0.125W | TME România | 0.01723 | 0.5169
17 | 680 | (LINK) (https://www.tme.eu/ro/details/smd0805-680r/rezistente-smd-0805/royal-ohm/0805s8j0681t5e/) | SMD0805-680R-5% | 0805S8J0681T5E | ROYAL OHM | rezistor | 30 |  | 1 | Rezistor SMD, chip, 0805, 680Ω, ±5%, 0.125W | TME România | 0.01723 | 0.5169
18 | 820 | (LINK) (https://www.tme.eu/ro/details/smd0805-820r/rezistente-smd-0805/royal-ohm/0805s8j0821t5e/) | SMD0805-820R-5% | 0805S8J0821T5E | ROYAL OHM | rezistor | 30 |  | 2 | Rezistor SMD, chip, 0805, 820Ω, ±5%, 0.125W | TME România | 0.01723 | 0.5169
19 | 910 | (LINK) (https://www.tme.eu/ro/details/rc0805jr-07910r/rezistente-smd-0805/yageo/rc0805jr-07910rl/) | SMD0805-910R-5% | RC0805JR-07910RL | YAGEO | rezistor | 40 |  | 7 | Rezistor SMD, chip, 0805, 910Ω, ±5%, 0.125W | TME România | 0.0261 | 1.044
20 | 1k | (LINK) (https://www.tme.eu/ro/details/smd0805-1k/rezistente-smd-0805/royal-ohm/0805s8j0102t5e/) | SMD0805-1K-5% | 0805S8J0102T5E | ROYAL OHM | rezistor | 100 |  | 2 | Rezistor SMD, chip, 0805, 1kΩ, ±5%, 0.125W | TME România | 0.01723 | 1.723
21 | 1.5k | (LINK) (https://www.tme.eu/ro/details/wf08p-1k5-5%25/rezistente-smd-0805/walsin/wf08p152jtl/) | SMD0805-1K5-5% | WF08P152JTL | WALSIN | rezistor | 40 |  |  | Rezistor SMD, chip, 0805, 1.5kΩ, ±5%, 0.125W | TME România | 0.0172 | 0.688
22 | 1.8k | (LINK) (https://www.tme.eu/ro/details/smd0805-1k8/rezistente-smd-0805/royal-ohm/0805s8j0182t5e/) | SMD0805-1K8-5% | 0805S8J0182T5E | ROYAL OHM | rezistor | 30 |  |  | Rezistor SMD, chip, 0805, 1.8kΩ, ±5%, 0.125W | TME România | 0.01723 | 0.5169
23 | 2k | (LINK) (https://www.tme.eu/ro/details/smd0805-2k/rezistente-smd-0805/royal-ohm/0805s8j0202t5e/) | SMD0805-2K-5% | 0805S8J0202T5E | ROYAL OHM | rezistor | 80 |  |  | Rezistor SMD, chip, 0805, 2kΩ, ±5%, 0.125W | TME România | 0.01723 | 1.3784
24 | 2.2k | (LINK) (https://www.tme.eu/ro/details/smd0805-2k2/rezistente-smd-0805/royal-ohm/0805s8j0222t5e/) | SMD0805-2K2-5% | 0805S8J0222T5E | ROYAL OHM | rezistor | 30 |  |  | Rezistor SMD, chip, 0805, 2.2kΩ, ±5%, 0.125W | TME România | 0.01723 | 0.5169
25 | 2.7k | (LINK) (https://www.tme.eu/ro/details/smd0805-2k7/rezistente-smd-0805/royal-ohm/0805s8j0272t5e/) | SMD0805-2K7-5% | 0805S8F2701T5E | ROYAL OHM | rezistor | 30 |  | 1 | Rezistor SMD, chip, 0805, 2.7kΩ, ±5%, 0.125W | TME România | 0.01723 | 0.5169
26 | 3.3k | (LINK) (https://www.tme.eu/ro/details/smd0805-3k3/rezistente-smd-0805/royal-ohm/0805s8j0332t5e/) | SMD0805-3K3-5% | 0805S8J0332T5E | ROYAL OHM | rezistor | 20 |  |  | Rezistor SMD, chip, 0805, 3.3kΩ, ±5%, 0.125W | TME România | 0.01723 | 0.3446
27 | 3.9k | (LINK) (https://www.tme.eu/ro/details/smd0805-3k9/rezistente-smd-0805/royal-ohm/0805s8j0392t5e/) | SMD0805-3K9-5% | 0805S8J0392T5E | ROYAL OHM | rezistor | 20 |  | 5 | Rezistor SMD, chip, 0805, 3.9kΩ, ±5%, 0.125W | TME România | 0.01723 | 0.3446
28 | 4.7k | (LINK) (https://www.tme.eu/ro/details/smd0805-4k7/rezistente-smd-0805/royal-ohm/0805s8j0472t5e/) | SMD0805-4K7-5% | 0805S8J0472T5E | ROYAL OHM | rezistor | 30 |  | 1 | Rezistor SMD, chip, 0805, 4.7kΩ, ±5%, 0.125W | TME România | 0.01723 | 0.5169
29 | 5.6k | (LINK) (https://www.tme.eu/ro/details/smd0805-5k6/rezistente-smd-0805/royal-ohm/0805s8j0562t5e/) | SMD0805-5K6-5% | 0805S8J0562T5E | ROYAL OHM | rezistor | 40 |  | 1 | Rezistor SMD, chip, 0805, 5.6kΩ, ±5%, 0.125W | TME România | 0.01723 | 0.6892
30 | 6.8k | (LINK) (https://www.tme.eu/ro/details/rc0805jr-076k8/rezistente-smd-0805/yageo/rc0805jr-076k8l/) | SMD0805-6K8-5% | RC0805JR-076K8L | YAGEO | rezistor | 20 |  |  | Rezistor SMD, chip, 0805, 6.8kΩ, ±5%, 0.125W | TME România | 0.0261 | 0.522
31 | 8.2k | (LINK) (https://www.tme.eu/ro/details/smd0805-8k2/rezistente-smd-0805/royal-ohm/0805s8j0822t5e/) | SMD0805-8K2-5% | 0805S8J0822T5E | ROYAL OHM | rezistor | 30 |  |  | Rezistor SMD, chip, 0805, 8.2kΩ, ±5%, 0.125W | TME România | 0.01723 | 0.5169
32 | 9.1k | (LINK) (https://www.tme.eu/ro/details/smd0805-9k1/rezistente-smd-0805/royal-ohm/0805s8j0912t5e/) | SMD0805-9K1-5% | 0805S8J0912T5E | ROYAL OHM | rezistor | 20 |  |  | Rezistor SMD, chip, 0805, 9.1kΩ, ±5%, 0.125W | TME România | 0.01723 | 0.3446
33 | 10k | (LINK) (https://www.tme.eu/ro/details/smd0805-10k/rezistente-smd-0805/royal-ohm/0805s8j0103t5e/) | SMD0805-10K-5% | 0805S8J0103T5E | ROYAL OHM | rezistor | 100 |  | 2 | Rezistor SMD, chip, 0805, 10kΩ, ±5%, 0.125W | TME România | 0.01723 | 1.723
34 | 15k | (LINK) (https://www.tme.eu/ro/details/smd0805-15k/rezistente-smd-0805/royal-ohm/0805s8j0153t5e/) | SMD0805-15K-5% | 0805S8J0153T5E | ROYAL OHM | rezistor | 30 |  |  | Rezistor SMD, chip, 0805, 15kΩ, ±5%, 0.125W | TME România | 0.01723 | 0.5169
35 | 22k | (LINK) (https://www.tme.eu/ro/details/smd0805-22k/rezistente-smd-0805/royal-ohm/0805s8j0223t5e/) | SMD0805-22K-5% | 0805S8J0223T5E | ROYAL OHM | rezistor | 30 |  |  | Rezistor SMD, chip, 0805, 22kΩ, ±5%, 0.125W | TME România | 0.01723 | 0.5169
36 | 47k | (LINK) (http://www.tme.eu/ro/details/smd0805-47k/rezistente-smd-0805/royal-ohm/0805s8j0473t5e/) | SMD0805-47K-5% | 0805S8J0473T5E | ROYAL OHM | rezistor | 40 |  |  | Rezistor: thick film; SMD; 0805; 47kΩ; 0,125W; ±5%; -55÷125°C | TME România | 0.01723 | 0.6892
37 | 68k | (LINK) (https://www.tme.eu/ro/details/smd0805-68k/rezistente-smd-0805/royal-ohm/0805s8j0683t5e/) | SMD0805-68K-5% | 0805S8J0683T5E | ROYAL OHM | rezistor | 20 |  |  | Rezistor SMD, chip, 0805, 68kΩ, ±5%, 0.125W | TME România | 0.01723 | 0.3446
38 | 100k | (LINK) (https://www.tme.eu/ro/details/smd0805-100k/rezistente-smd-0805/royal-ohm/0805s8j0104t5e/) | SMD0805-100K-5% | 0805S8J0104T5E | ROYAL OHM | rezistor | 100 |  |  | Rezistor SMD, chip, 0805, 100kΩ, ±5%, 0.125W | TME România | 0.01723 | 1.723
39 | 150k | (LINK) (http://www.tme.eu/ro/details/smd0805-150k/rezistente-smd-0805/royal-ohm/0805s8j0154t5e/) | SMD0805-150K-5% | 0805S8J0154T5E | ROYAL OHM | rezistor | 30 |  |  | Rezistor SMD, chip, 0805, 150kΩ, ±5%, 0.125W | TME România | 0.01723 | 0.5169
40 | 180k | (LINK) (http://www.tme.eu/ro/details/smd0805-180k/rezistente-smd-0805/royal-ohm/0805s8j0184t5e/) | SMD0805-180K-5% | 0805S8J0184T5E | ROYAL OHM | rezistor | 30 |  |  | Rezistor SMD, chip, 0805, 180kΩ, ±5%, 0.125W | TME România | 0.01723 | 0.5169
41 | 220k | (LINK) (https://www.tme.eu/ro/details/smd0805-220k/rezistente-smd-0805/royal-ohm/0805s8j0224t5e/) | SMD0805-220K-5% | 0805S8J0224T5E | ROYAL OHM | rezistor | 30 |  |  | Rezistor SMD, chip, 0805, 220kΩ, ±5%, 0.125W | TME România | 0.01723 | 0.5169
42 | 330k | (LINK) (https://www.tme.eu/ro/details/smd0805-330k/rezistente-smd-0805/royal-ohm/0805s8j0334t5e/) | SMD0805-330K-5% | 0805S8J0334T5E | ROYAL OHM | rezistor | 30 |  |  | Rezistor SMD, chip, 0805, 330kΩ, ±5%, 0.125W | TME România | 0.01723 | 0.5169
43 | 390k | (LINK) (https://www.tme.eu/ro/details/smd0805-390k/rezistente-smd-0805/royal-ohm/0805s8j0394t5e/) | SMD0805-390K-5% | 0805S8J0394T5E | ROYAL OHM | rezistor | 30 |  |  | Rezistor SMD, chip, 0805, 390kΩ, ±5%, 0.125W | TME România | 0.01723 | 0.5169
44 | 510k | (LINK) (https://www.tme.eu/ro/details/smd0805-510k/rezistente-smd-0805/royal-ohm/0805s8j0514t5e/) | SMD0805-510K-5% | 0805S8J0514T5E | ROYAL OHM | rezistor | 30 |  |  | Rezistor SMD, chip, 0805, 510kΩ, ±5%, 0.125W | TME România | 0.01723 | 0.5169
45 | 1M | (LINK) (https://www.tme.eu/ro/details/crcw08051m00jntabc/rezistente-smd-0805/vishay/) | SMD0805-1M-5% | CRCW08051M00JNTABC | VISHAY | rezistor | 0 |  |  | Rezistor SMD, chip, 0805, 1MΩ, ±5%, 0.125W | TME România | 0.01151 | 0
46 | 2M | (LINK) (http://www.tme.eu/ro/details/smd0805-2m/rezistente-smd-0805/royal-ohm/0805waj-2m-t5e/) | SMD0805-2M7 5% | 0805WAJ 2M T5E | ROYAL OHM | rezistor | 0 |  |  | Rezistor SMD, chip, 0805, 2MΩ, ±1%, 0.125W | TME România | 0.01723 | 0
47 | 5,1M | (LINK) (http://www.tme.eu/ro/details/smd0805-5m1/rezistente-smd-0805/royal-ohm/0805s8j0515t5e/) | SMD0805-5M1 5% | RC0805FR-075M1 | Yageo | rezistor | 0 |  |  | Rezistor SMD, chip, 0805, 5.1MΩ, ±1%, 0.125W | TME România | 0.01723 | 0
48 | 10M | (LINK) (https://www.tme.eu/ro/details/0805s8j0106t5e/rezistente-smd-0805/royal-ohm/) | SMD0805-10M 5% | 0805S8J0106T5E | ROYAL OHM | rezistor | 0 |  |  | Rezistor SMD, chip, 0805, 10MΩ, ±5%, 0.125W | TME România | 0.01723 | 0
49 | 100ohm | (LINK) (https://www.tme.eu/ro/details/ts53yl100r/trimere-smd-cu-o-singura-tura/vishay/ts53yl101mr10/) | 1804GSMD-100R | 1804GSMD-100R | SR PASSIVES | potențiometru | 15 |  |  | Potențiome-tru liniar, simplă tură, SMD, 100Ω, ±10%, 100ppm/°C, 0.25W | TME România | 3.77 | 56.55
50 | 500ohm | (LINK) (https://www.tme.eu/ro/details/ts53yl500r/trimere-smd-cu-o-singura-tura/vishay/ts53yl501mr10/) | 1804GSMD-500R | 1804GSMD-500R | VISHAY | potențiometru | 0 |  |  | Potențiome-tru liniar, simplă tură, SMD, 500Ω, ±10%, 100ppm/°C, 0.25W | TME România | 2.19 | 0
51 | 2k | (LINK) (https://www.tme.eu/ro/details/ts53yl2k/trimere-smd-cu-o-singura-tura/vishay/ts53yl202mr10/) | TS53YL202MR10 | TS53YL202MR10 | VISHAY | potențiometru | 0 |  |  | Potențiome-tru liniar, simplă tură, SMD, 2kΩ, ±20%, 100ppm/°C, 0.25W | TME România | 2.84 | 0
52 | 5k | (LINK) (http://www.tme.eu/ro/details/3314g-1-502e/trimere-smd-cu-o-singura-tura/bourns/) | 3314G-1-502E | 3314G-1-502E | BOURNS | potențiometru | 40 |  | 2 | Potențiome-tru liniar, simplă tură, SMD, 5kΩ, ±20%, 100ppm/°C, 0.25W | TME România | 3.45 | 138
53 | 10k | (LINK) (http://www.tme.eu/ro/details/3314g-1-103e/trimere-smd-cu-o-singura-tura/bourns/) | 3314G-1-103E | 3314G-1-103E | BOURNS | potențiometru | 20 |  |  | Potențiome-tru liniar, simplă tură, SMD, 10kΩ, ±20%, 100ppm/°C, 0.25W | TME România | 3.0573 | 61.146
54 | 50k | (LINK) (http://www.tme.eu/ro/details/3314g-1-503e/trimere-smd-cu-o-singura-tura/bourns/) | 3314G-1-503E | 3314G-1-503E | BOURNS | potențiometru | 0 |  |  | Potențiome-tru liniar, simplă tură, SMD, 50kΩ, ±20%, 100ppm/°C, 0.25W | TME România | 2.84 | 0
55 | 100k | (LINK) (http://www.tme.eu/ro/details/ts53yl100k/trimere-smd-cu-o-singura-tura/vishay/ts53yl104mr10/) | TS53YL104MR10 | TS53YL104MR10 | VISHAY | potențiometru | 10 |  |  | Potențiome-tru liniar, simplă tură, SMD, 100kΩ, ±20%, 100ppm/°C, 0.25W | TME România | 2.61 | 26.1
56 | 500k | (LINK) (http://www.tme.eu/ro/details/3314g-1-504e/trimere-smd-cu-o-singura-tura/bourns/) | 3314G-1-504E | 3314G-1-504E | BOURNS | potențiometru | 0 |  |  | Potențiome-tru liniar, simplă tură, SMD, 500kΩ, ±10%, 100ppm/°C, 0.25W | TME România | 2.8802 | 0
 | TOTAL - Componente pasive (rezistoare de valori fixe şi reglabile) |  |  |  |  |  |  |  |  | FARA TVA = | 308.4514 | CU TVA= | 382.479736
57 | 4.7pF | (LINK) (http://www.tme.eu/ro/details/cc0805crnpo94r7/condensatoare-mlcc-smd-0805/yageo/cc0805crnpo9bn4r7/) | CC0805CRNPO9BN4R7 | CC0805CRNPO9BN4R7 | YAGEO | condensator | 20 |  |  | ceramic; MLCC; 4,7pF; 50V; C0G; ±0,25pF; SMD; 0805 | TME România | 0.16643 | 3.3286
58 | 10pF | (LINK) (http://www.tme.eu/ro/details/cc0805jrnpo9100/condensatoare-mlcc-smd-0805/yageo/cc0805jrnpo9bn100/) | CC0805JRNPO9BN100 | CC0805JRNPO9BN100 | YAGEO | condensator | 20 |  |  | ceramic; MLCC; 10pF; 50V; C0G; ±5%; SMD; 0805 | TME România | 0.1649 | 3.298
59 | 47pF | (LINK) (http://www.tme.eu/ro/details/cl21c470jbannnc/condensatoare-mlcc-smd-0805/samsung/) | CL21C470JBANNNC | CL21C470JBANNNC | SAMSUNG | condensator | 20 |  |  | Condensator: ceramic; MLCC; 47pF; 50V; C0G; ±5%; SMD; 0805; -55÷125°C | TME România | 0.11097 | 2.2194
60 | 100pF | (LINK) (http://www.tme.eu/ro/details/cl21c101jbannnc/condensatoare-mlcc-smd-0805/samsung/) | CL21C101JBANNNC | CL21C101JBANNNC | SAMSUNG | condensator | 20 |  |  | Condensator: ceramic; MLCC; 100pF; 50V; C0G; ±5%; SMD; 0805 | TME România | 0.05427 | 1.0854
61 | 470pF | (LINK) (https://www.tme.eu/ro/details/cl21c471jbannnc/condensatoare-mlcc-smd-0805/samsung/) | CL21C471JBANNNC | CL21C471JBANNNC | SAMSUNG | condensator | 20 |  |  | Condensator: ceramic; MLCC; 470pF; 50V; X7R; ±10%; SMD; 0805 | TME România | 0.12123 | 2.4246
62 | 1nF | (LINK) (https://www.tme.eu/ro/details/cc0805jrnpo9102/condensatoare-mlcc-smd/yageo/cc0805jrnpo9bn102/) | CL21C102JBCNNNC | CL21C102JBCNNNC | SAMSUNG | condensator | 0 |  |  | Condensator MLCC, SMD, 0805, 1nF, ±5%, 50V, C0G | TME România | 0.06487 | 0
63 | 2.2nF | (LINK) (https://www.tme.eu/ro/details/cl21b222jbannnc/condensatoare-mlcc-smd-0805/samsung/) | CL21B222JBANNNC | CL21B222JBANNNC | SAMSUNG | condensator | 0 |  |  | Condensator: ceramic; MLCC; 2,2nF; 50V; X7R; ±10%; SMD; 0805 | TME România | 0.1485 | 0
64 | 4.7nF | (LINK) (https://www.tme.eu/ro/details/cl21b472kbannnc/condensatoare-mlcc-smd-0805/samsung/) | CL21B472KBANNNC | CL21B472KBANNNC | SAMSUNG | condensator | 0 |  |  | Condensator MLCC, SMD, 0805, 4.7nF, ±5%, 50V, X7R | TME România | 0.08943 | 0
65 | 5.6nF | (LINK) (https://www.tme.eu/ro/details/cl21b562kbannnc/condensatoare-mlcc-smd-0805/samsung/) | CL21B562KBANNNC | CL21B562KBANNNC | SAMSUNG | condensator | 0 |  |  | Condensator MLCC, SMD, 0805, 5.6nF, ±5%, 50V, X7R | TME România | 0.04517 | 0
66 | 10nF | (LINK) (https://www.tme.eu/ro/details/cl21b103kbannnd/condensatoare-mlcc-smd-0805/samsung/) | CL21B103KBANNND | CL21B103KBANNND | SAMSUNG | condensator | 40 |  |  | Condensator MLCC, SMD, 0805, 10nF, ±5%, 50V, X7R | TME România | 0.06093 | 2.4372
67 | 22nF | (LINK) (http://www.tme.eu/ro/details/cl21b223kcfnnne/condensatoare-mlcc-smd-0805/samsung/) | CL21B223KBANNNC | CL21B223KBANNNC | SAMSUNG | condensator | 0 |  |  | Condensator: ceramic; MLCC; 22nF; 100V; X7R; ±10%; SMD; 0805 | TME România | 0.13823 | 0
68 | 33nF | (LINK) (https://www.tme.eu/ro/details/vj0805y333kxacw1bc/condensatoare-mlcc-smd-0805/vishay/) | VJ0805Y333KXACW1BC | VJ0805Y333KXACW1BC | VISHAY | condensator | 0 |  |  | Condensator: ceramic; MLCC; 33nF; 50V; X7R; ±10%; SMD; 0805 | TME România | 0.05417 | 0
69 | 100nF | (LINK) (https://www.tme.eu/ro/details/cl21b104kbcnnnc/condensatoare-mlcc-smd/samsung/) | CL21B104KBCNNNC | CL21B104KBCNNNC | SAMSUNG | condensator | 40 |  |  | ceramic; MLCC; 100nF; 50V; X7R; ±10%; SMD; 0805 | TME România | 0.3759 | 15.036
70 | 220nF | (LINK) (http://www.tme.eu/ro/details/cl21b224kafnnne/condensatoare-mlcc-smd-0805/samsung/) | CL21B224KAFNNNE | CL21B224KAFNNNE | SAMSUNG | condensator | 0 |  |  | Condensator: ceramic; MLCC; 220nF; 25V; X7R; ±10%; SMD; 0805 | TME România | 0.10247 | 0
71 | 330nF | (LINK) (https://www.tme.eu/ro/details/grm219r71h334ka88d/condensatoare-mlcc-smd-0805/murata/) | GRM219R71H334KA88D | GRM219R71H334KA88D | MURATA | condensator | 0 |  |  | Condensator: ceramic; MLCC; 330nF; 50V; X7R; ±10%; SMD; 0805 | TME România | 0.5972 | 0
72 | 470nF | (LINK) (https://www.tme.eu/ro/details/cc0805mry5v8474/condensatoare-mlcc-smd-0805/yageo/cc0805mry5v8bb474/) | CC0805MRY5V8474 | CC0805MRY5V8BB474 | YAGEO | condensator | 0 |  |  | Condensator: ceramic; MLCC; 470nF; 50V; Y5V; -20÷+80%; SMD; 0805 | TME România | 0.0758 | 0
73 | 1uF | (LINK) (https://www.tme.eu/ro/details/cl21b105kbfnnng/condensatoare-mlcc-smd-0805/samsung/) | CL21B105KBFNNNG | CL21B105KBFNNNG | SAMSUNG | condensator | 20 |  |  | Condensator: ceramic; MLCC; 1uF; 50V; X7R; ±20%; SMD; 0805 | TME România | 0.25253 | 5.0506
74 | 2.2uF | (LINK) (https://www.tme.eu/ro/details/grm21br61h225ka73l/condensatoare-mlcc-smd-0805/murata/) | GRM21BR61H225KA73L | GRM21BR61H225KA73L | MURATA | condensator | 20 |  |  | Condensator: ceramic; MLCC; 2,2uF; 25V; X5R; ±10%; SMD; 0805 | TME România | 0.4486 | 8.972
75 | 4.7uF | (LINK) (https://www.tme.eu/ro/details/cl21a475kaqnnng/condensatoare-mlcc-smd-0805/samsung/) | CL21A475KAQNNNG | CL21A475KAQNNNG | SAMSUNG | condensator | 20 |  |  | ceramic; MLCC; 4,7uF; 25V; X5R; ±10%; SMD; 0805 | TME România | 0.25373 | 5.0746
76 | 10uF | (LINK) (https://www.tme.eu/ro/details/eee1ha100sp/condensatoare-electrolitice-smd/panasonic/) | EEE1HA100SP | EEE1HA100SP | PANASONIC | condensator | 16 |  |  | Condensator: electrolitic; SMD; 10uF; 50V | TME România | 0.2284 | 3.6544
 | TOTAL - Componente pasive (condensatoare) |  |  |  |  |  |  |  |  | FARA TVA = | 52.5808 | CU TVA= | 65.200192
77 | 4148 | (LINK) (http://www.tme.eu/ro/details/1n4148-0805/diode-universale-smd/dc-components/cd4148ws0805c/) | 1N4148-0805 | CD4148WS(0805C) | DC Components | diodă pn | 40 |  |  | Diodă comutație, SMD, 0805, 300mA, 100V | TME România | 0.04555 | 1.822
78 | LED | (LINK) (https://www.tme.eu/ro/details/of-smd2012b/diode-led-smd-colorate/optoflash/) | OF-SMD2012B | OF-SMD2012B | OPTOFLASH | LED | 15 |  | 2 | LED albastru, SMD, 0805, 150-200mcd, 476nm, 120° | TME România | 0.1264 | 1.896
79 | 2.7V | (LINK) (https://www.tme.eu/ro/details/bzx84-c2v7.215/diode-zener-smd/nexperia/bzx84-c2v7-215/) | BZX84C2V7 | BZX84-C2V7LT1G | ON Semiconductor | diodă Zener | 5 |  | 1 | Diodă Zener, SMD, SOT23, 2,7V, ±5%, 0.25W | TME România | 0.05732 | 0.2866
80 | 5.1V | (LINK) (https://www.tme.eu/ro/details/bzx84-c5v1.215/diode-zener-smd/nexperia/) | BZX84C5V1 | BZX84-C5V1 | NEXPERIA | diodă Zener | 10 |  |  | Diodă Zener, SMD, SOT23, 5,1V, ±5%, 0.3W | TME România | 0.06245 | 0.6245
81 | 5.6V | (LINK) (https://www.tme.eu/ro/details/bzx84b5v6-dio/diode-zener-smd/diotec-semiconductor/bzx84b5v6/) | BZX84B5V6 | BZX84B5V6 | DIOTEC SEMICONDUCTOR | diodă Zener | 10 |  |  | Diodă Zener, SMD, SOT23, 5,6V, ±5%, 0.3W | TME România | 0.0839 | 0.839
82 | 6.2V | (LINK) (https://www.tme.eu/ro/details/bzx84-c6v2.215/diode-zener-smd/nexperia/) | BZX84C6V2 | BZX84-C6V2 | NEXPERIA | diodă Zener | 5 |  | 1 | Diodă Zener, SMD, SOT23, 6.2V, ±5%, 0.3W | TME România | 0.06618 | 0.3309
83 | 6.8V | (LINK) (https://www.tme.eu/ro/details/bzx84-c6v8.215/diode-zener-smd/nexperia/) | BZX84C6V8 | BZX84-C6V8 | NEXPERIA | diodă Zener | 0 |  |  | Diodă Zener, SMD, SOT23, 6.8V, ±5%, 0.3W | TME România | 0.05686 | 0
84 | 8.2V | (LINK) (https://www.tme.eu/ro/details/bzx84-c8v2.215/diode-zener-smd/nexperia/) | BZX84C8V2 | BZX84-C8V2 | NEXPERIA | diodă Zener | 5 |  |  | Diodă Zener, SMD, SOT23, 8.2V, ±5%, 0.3W | TME România | 0.05686 | 0.2843
85 | 10V | (LINK) (https://www.tme.eu/ro/details/bzx84-c10.215/diode-zener-smd/nexperia/) | BZX84C10 | BZX84-C10 | NEXPERIA | diodă Zener | 5 |  |  | Diodă Zener, SMD, SOT23, 10V, ±5%, 0.3W | TME România | 0.05686 | 0.2843
86 | PNP | (LINK) (http://www.tme.eu/ro/details/bc856b-dio/tranzistori-smd-pnp/diotec-semiconductor/bc856b/) | BC856B | BC856B | DIOTEC | tranzistor bipolar | 80 |  | 4 | Tranzistor bipolar PNP, SMD, SOT23, 80V, 100mA | TME România | 0.04055 | 3.244
87 | NPN | (LINK) (https://www.tme.eu/ro/details/bc846b-dio/tranzistori-smd-npn/diotec-semiconductor/bc846b/) | BC846B | BC846B | DIOTEC | tranzistor bipolar | 80 |  | 4 | Tranzistor bipolar NPN, SMD, SOT23, 65V, 100mA | TME România | 0.03379 | 2.7032
89 | N-JFET | (LINK) (http://www.tme.eu/ro/details/mmbfj309lt1g/tranzistori-canal-n-smd/on-semiconductor/) | MMBFJ309LT1G | MMBFJ309LT1G | ON Semiconductor | tranzistor NJFET | 40 |  |  | Tranzistor N-JFET, SMD, SOT23, 25V, 30mA | TME România | 0.8063 | 32.252
90 | P-JFET | (LINK) (http://www.tme.eu/ro/details/mmbfj177lt1g/tranzistori-canal-p-smd/on-semiconductor/) | MMBFJ177LT1G | MMBFJ177LT1G | ON Semiconductor | tranzistor PJFET | 15 |  |  | Tranzistor P-JFET, SMD, SOT23, 30V, 20mA | TME România | 0.8808 | 13.212
91 | NPN | (LINK) (http://www.tme.eu/ro/details/bc817-25-dio/tranzistori-smd-npn/diotec-semiconductor/bc817-25/) | BC817-25-DIO | BC817-25-DIO | NXP | tranzistor bipolar | 10 |  |  | Tranzistor bipolar NPN, SMD, SOT23, 45V, 800mA | TME România | 0.0494 | 0.494
93 | PNP | (LINK) (http://www.tme.eu/ro/details/bc807-25-dio/tranzistori-smd-pnp/diotec-semiconductor/bc807-25/) | BC807-25-DIO | BC807-25-DIO | NXP | tranzistor bipolar | 10 |  |  | Tranzistor bipolar PNP, SMD, SOT23, 45V, 800mA | TME România | 0.05406 | 0.5406
94 | NPN | (LINK) (http://www.tme.eu/ro/details/mjd31cg/tranzistori-smd-npn/on-semiconductor/) | MJD31CG | MJD31CG | ON Semiconductor | tranzistor bipolar | 15 |  | 1 | Tranzistor bipolar NPN, SMD, DPACK, 100V, 3A, 15W | TME România | 0.7037 | 10.5555
96 | PNP | (LINK) (http://www.tme.eu/ro/details/mjd32cg/tranzistori-smd-pnp/on-semiconductor/) | MJD32CG | MJD32CG | ON Semiconductor | tranzistor bipolar | 15 |  |  | Tranzistor bipolar PNP, SMD, DPACK, 100V, 3A, 15W | TME România | 0.783 | 11.745
97 | Nmos | (LINK) (http://www.tme.eu/ro/details/irfr120npbf/tranzistori-canal-n-smd/international-rectifier/) | IRFR120NPBF | IRFR120NPBF | International Rectifier | tranzistor NMOS | 10 |  |  | Tranzistor N-MOSFET, SMD, DPAK, 100V, 9.1A, 20V, 39W | TME România | 1.03 | 10.3
 | TOTAL - Componente semiconductoare (tranzistoare bipolare şi cu efect de câmp, diode, LED, etc.) |  |  |  |  |  |  |  |  | FARA TVA = | 118.7139 | CU TVA= | 147.205236
98 | Conn2p | (LINK) (http://www.tme.eu/ro/details/zl301-40p/pini-cu-benzi-si-soclu/ninigi/) | ZL301-40P | ZL301-40P | NINIGI | Sir pini, pas 2,54mm, SMD | 6 |  | 1 | Sir pini, pas 2,54mm, SMD, tip tata, bareta de 40 pini | TME România | 2.3027 | 13.8162
99 | FUSE | (LINK) (http://www.tme.eu/ro/details/3413.0116.11/sigurante-smd-1206-ultrarapide/schurter/) | 3413.0116.11 | 3413.0116.11 | SCHURTER | sigu-ranță | 0 |  |  | Siguranță sticlă, SMD, 1206, 1.25A, 48mΩ | TME România | 0 | 0
 | Total - Conectică, sigurante fuzibile, etc. |  |  |  |  |  |  |  |  | FARA TVA = | 13.8162 | CU TVA= | 17.132088
 | Total general |  |  |  |  |  |  |  |  | FARA TVA = | 493.5623 | CU TVA= | 587.339137

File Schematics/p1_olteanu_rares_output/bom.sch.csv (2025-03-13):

Item Number | Quantity | Value | Description | Part Number | Part Reference | Manufacturer Name | Manufacturer Part Number | ID | SKU | ALT_MPN | ALT_MFR
1 | 1 | BZX84-C6V2 |  |  | D1 |  |  | 1915
2 | 1 | BZX84-C2V7 |  |  | D2 |  |  | 1918
3 | 1 | CON2 |  |  | J1 |  |  | 1789
4 | 1 | CON2 |  |  | J2 |  |  | 1815
5 | 1 | MLED81 |  |  | LED1 |  |  | 1923
6 | 1 | MLED81 |  |  | LED2 |  |  | 1926
7 | 1 | 5k |  |  | P1 |  |  | 1742
8 | 1 | 5k |  |  | P2 |  |  | 1756
9 | 1 | QBC856B |  |  | Q1 |  |  | 1644
10 | 1 | QBC856B |  |  | Q2 |  |  | 1729
11 | 1 | QBC856B |  |  | Q3 |  |  | 1749
12 | 1 | QBC856B |  |  | Q4 |  |  | 1667
13 | 1 | QBC846B |  |  | Q5 |  |  | 1707
14 | 1 | QBC846B |  |  | Q6 |  |  | 1691
15 | 1 | QBC846B |  |  | Q7 |  |  | 1648
16 | 1 | QMJD31C |  |  | Q8 |  |  | 1903
17 | 1 | QBC846B |  |  | Q9 |  |  | 1671
18 | 1 | 1k |  |  | R1 |  |  | 1685
19 | 1 | 1k |  |  | R2 |  |  | 1720
20 | 1 | 1k |  |  | R3 |  |  | 1652
21 | 1 | 510 |  |  | R4 |  |  | 1717
22 | 1 | 330 |  |  | R5 |  |  | 1733
23 | 1 | 470 |  |  | R6 |  |  | 1753
24 | 1 | 1k |  |  | R7 |  |  | 1723
25 | 1 | 1k |  |  | R8 |  |  | 1736
26 | 1 | 1k |  |  | R9 |  |  | 1682
27 | 1 | 1.5k |  |  | R10 |  |  | 1711
28 | 1 | 2.7K |  |  | R11 |  |  | 1772
29 | 1 | 1.5k |  |  | R12 |  |  | 1763
30 | 1 | 4.7k |  |  | R13 |  |  | 1688
31 | 1 | 220 |  |  | R14 |  |  | 1695
32 | 1 | 1k |  |  | R15 |  |  | 1661
33 | 1 | 10K |  |  | R16 |  |  | 1704
34 | 1 | 10K |  |  | R17 |  |  | 1760
35 | 1 | 0.47 |  |  | R18 |  |  | 1701
36 | 1 | 680 |  |  | R19 |  |  | 1726
37 | 1 | 0.47 |  |  | R20 |  |  | 1746
38 | 1 | 5.6k |  |  | R21 |  |  | 1769
39 | 1 | 3.9k |  |  | R22 |  |  | 1779
40 | 1 | 3.9k |  |  | R23 |  |  | 1782
41 | 1 | 3.9k |  |  | R24 |  |  | 1766
42 | 1 | 0.47 |  |  | R25 |  |  | 1655
43 | 1 | 3.9k |  |  | R26 |  |  | 1785
44 | 1 | 3.9k |  |  | R27 |  |  | 1802
45 | 1 | 820 |  |  | R28 |  |  | 1679
46 | 1 | 820 |  |  | R29 |  |  | 1698

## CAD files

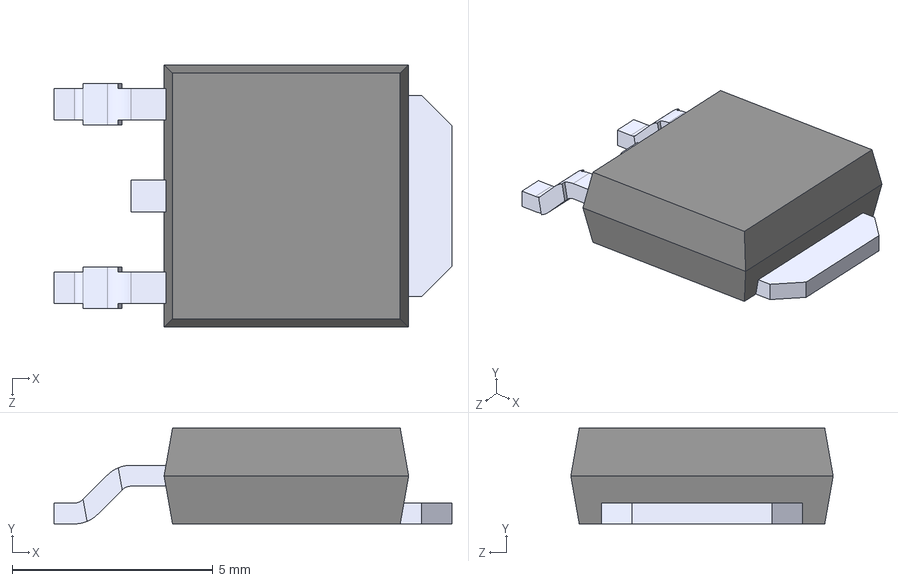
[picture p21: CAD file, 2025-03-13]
Schematics/MJD31CG.stp
9.92 x 2.39 x 6.54 mm
MAC4DCMT4G_5
MAC4DCMT4G
MAC4DCMT4G_4
MAC4DCMT4G_3
MAC4DCMT4G_2

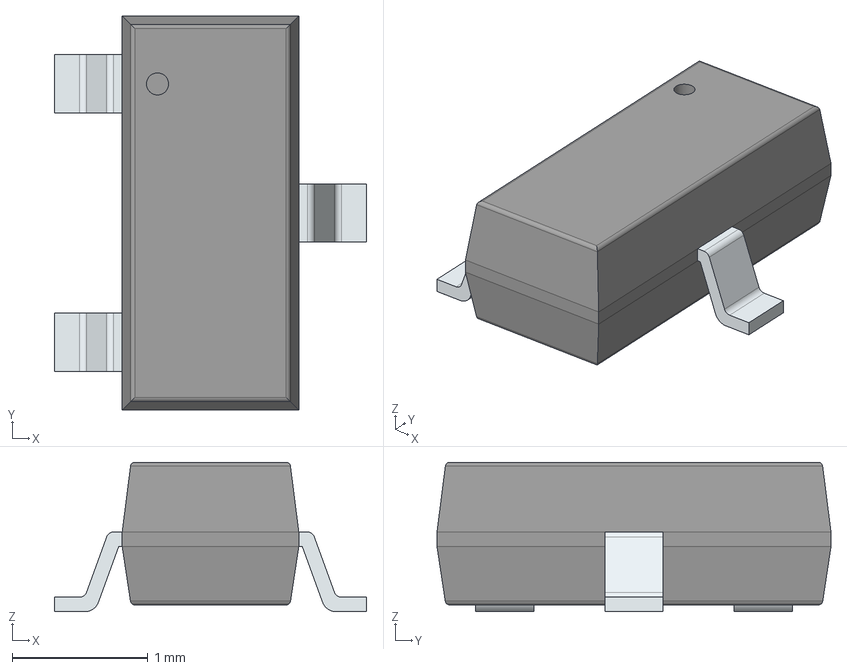
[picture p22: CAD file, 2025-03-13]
Schematics/BC846B.stp
2.30 x 2.90 x 1.10 mm
PinsArrayL
FilletPinR

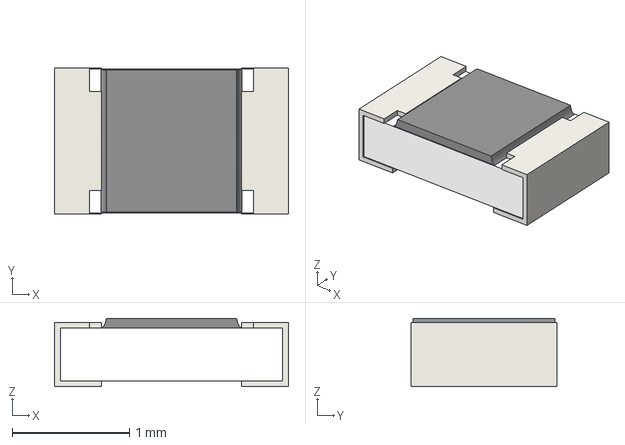
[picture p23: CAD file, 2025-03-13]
Schematics/res.stp
2.00 x 1.25 x 0.585 mm

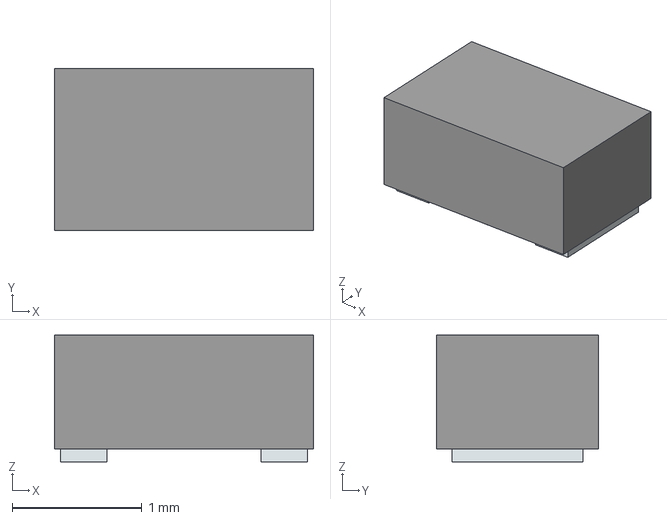
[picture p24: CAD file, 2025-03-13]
Schematics/OF-SMD2012B.stp
2.00 x 1.25 x 0.98 mm
Pins

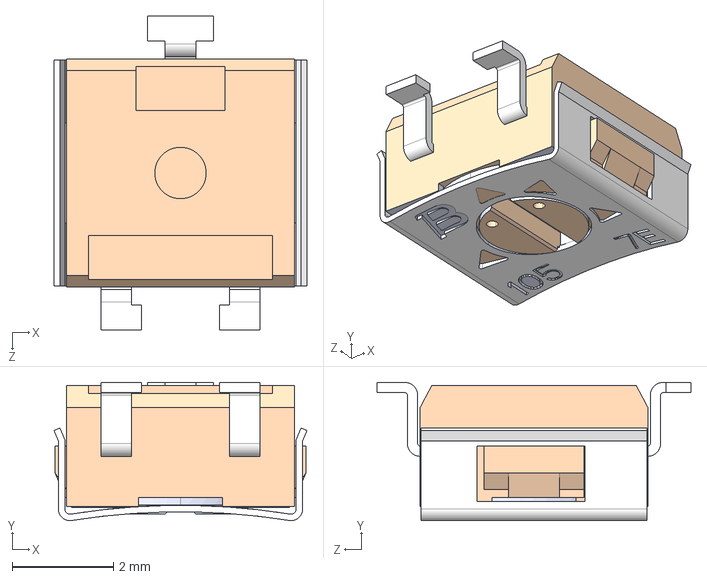
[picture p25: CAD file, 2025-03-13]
Schematics/3314G-1-103E.stp
5.00 x 2.73 x 6.20 mm

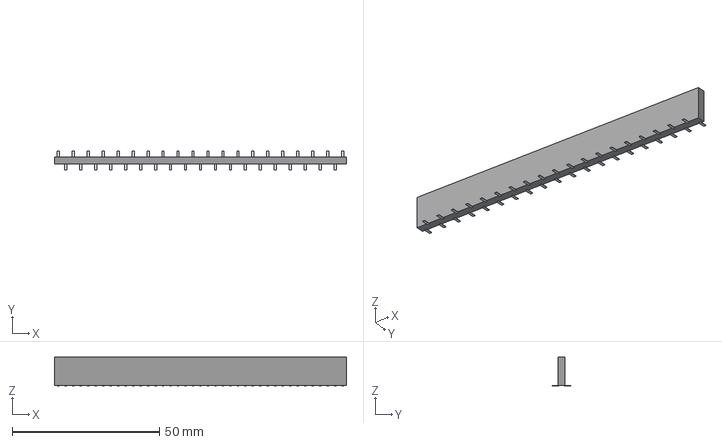
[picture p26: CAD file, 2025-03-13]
Schematics/ZL301-40P.stp
99.1 x 6.50 x 9.80 mm
Pins

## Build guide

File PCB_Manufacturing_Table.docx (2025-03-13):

General info document for PCB manufacturing
No. | Item Name | File Name | | | | | | Info / Remarks / Notes
| BOARD
1 | Board Name / Number | Olteanu Rares 434D 2024-2025 | | | | | | -
2 | Revision Date | 14.12.2024 | | | | | | -
3 | Board Size | 40 x 40 mm² | | | | | | -
4 | Board Quantity | 1 | | | | | | -
5 | Material / Dielectric Type | FR-4 | | | | | | -
6 | Board Thickness | 1.6 mm | | | | | | -
7 | Copper Thickness | 18 μm | | | | | | -
| LAYERS
8 | Number of Electrical Layers | 2 | | | | | | -
9 | Copper Layer TOP | TOP.art | | | | | | -
10 | Copper Layer BOTTOM | BOTTOM.art | | | | | | -
11 | Copper GND Plane | - | | | | | | -
12 | Copper PWR Plane | - | | | | | | -
13 | Copper INNER 1 | - | | | | | | -
14 | Copper INNER 2 | - | | | | | | -
15 | Solder Mask TOP | SMTOP.art | | | | | | -
16 | Solder Mask BOTTOM | SMBOT.art | | | | | | -
17 | Solder Paste TOP | SPTOP.art | | | | | | -
18 | Solder Paste BOTTOM | - | | | | | | -
19 | Peelable Mask TOP | - | | | | | | -
20 | Peelable Mask BOTTOM | - | | | | | | -
21 | Silk Screen TOP | SSTOP.art | | | | | | -
22 | Silk Screen BOTTOM | - | | | | | | -
23 | Board Outline | BO.art | | | | | | -
24 | Fabrication Drawing | FAB.art | | | | | | -
| MILLING & DRILLING
25 | Mill Drawing | - | | | | | | -
26 | Drill Drawing | - | | | | | | -
27 | N.C. Drill (for both PH & NPH) | - | | | | | | -
28 | N.C. Drill / Plated Holes (PH) | DRILL.drl | | | | | | -
29 | N.C. Drill / Non-Plated Holes (PH) | - | | | | | | -
| FINISHING
30 | Panelisation | - | | | | | | -
31 | Electrical Test | - | | | | | | -
32 | Copper Finishing | x | HASL | | OSP | | | ENIG
33 | Board Outline Machining | | Routing | | Milling | | x | V-Cutting
34 | Final remarks | - | | | | -

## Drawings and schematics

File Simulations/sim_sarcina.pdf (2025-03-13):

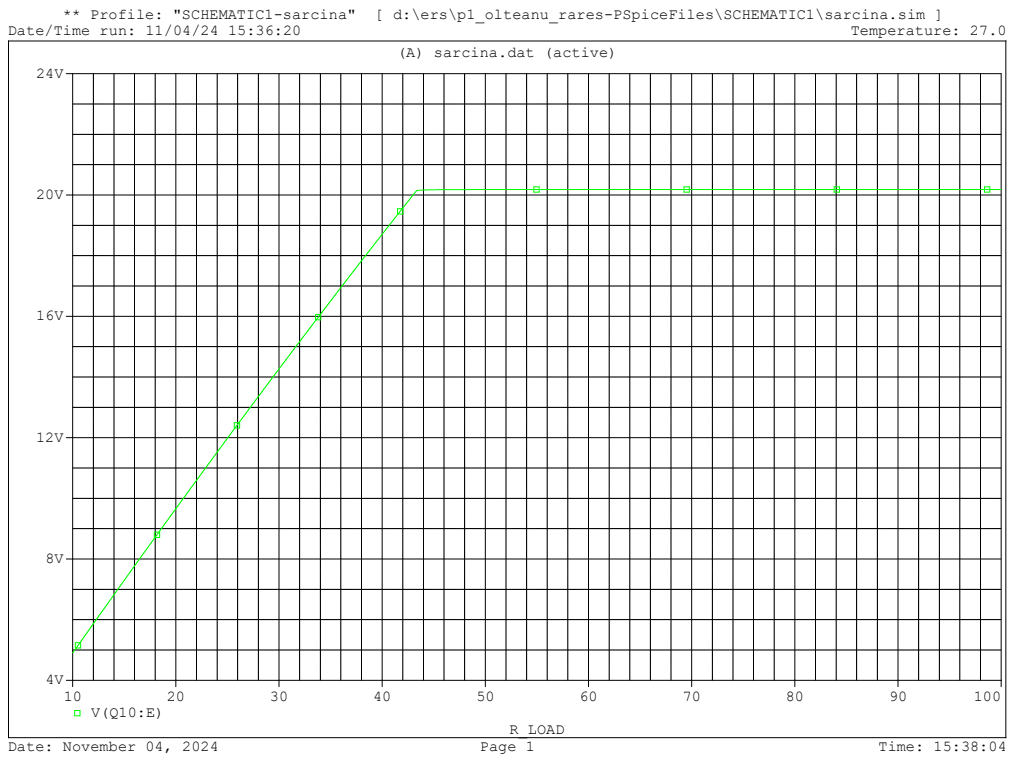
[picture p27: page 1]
Temperature: 27.0; Date: November 04, 2024; Page 1; Time: 15:38:04; R_LOAD

** Profile: "SCHEMATIC1-sarcina" [ d:\ers\p1_olteanu_rares-PSpiceFiles\SCHEMATIC1\sarcina.sim ]

Date/Time run: 11/04/24 15:36:20

(A) sarcina.dat (active)

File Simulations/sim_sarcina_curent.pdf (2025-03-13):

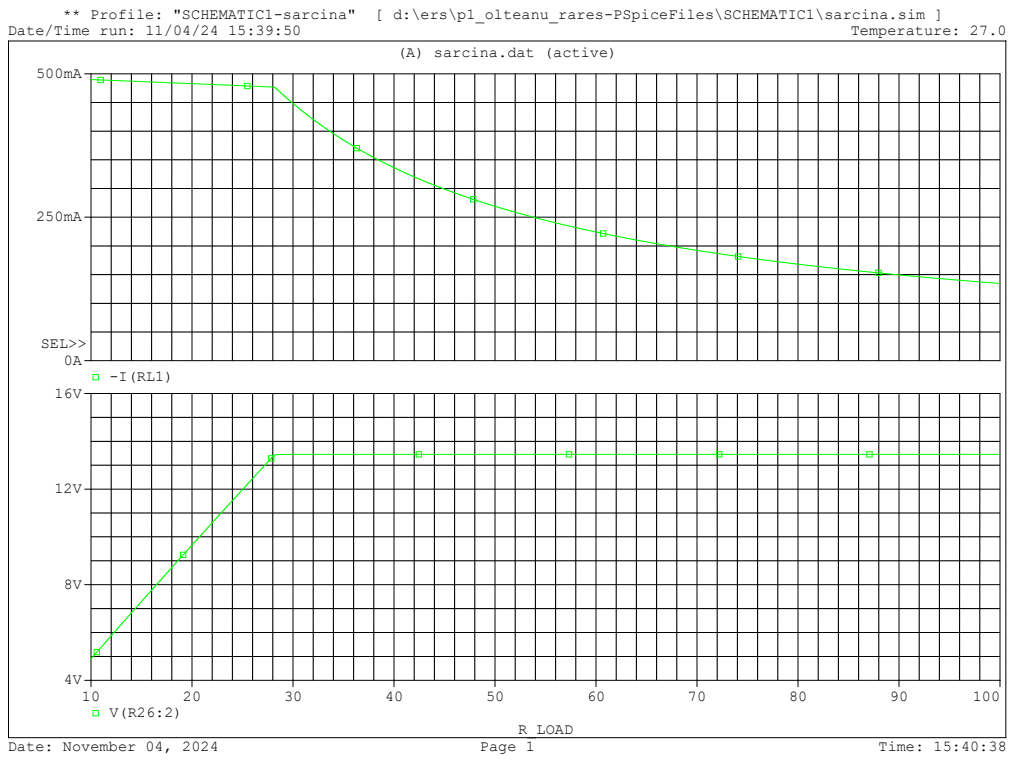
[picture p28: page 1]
Temperature: 27.0; Date: November 04, 2024; Page 1; Time: 15:40:38; R_LOAD; SEL>>

** Profile: "SCHEMATIC1-sarcina" [ d:\ers\p1_olteanu_rares-PSpiceFiles\SCHEMATIC1\sarcina.sim ]

Date/Time run: 11/04/24 15:39:50

(A) sarcina.dat (active)

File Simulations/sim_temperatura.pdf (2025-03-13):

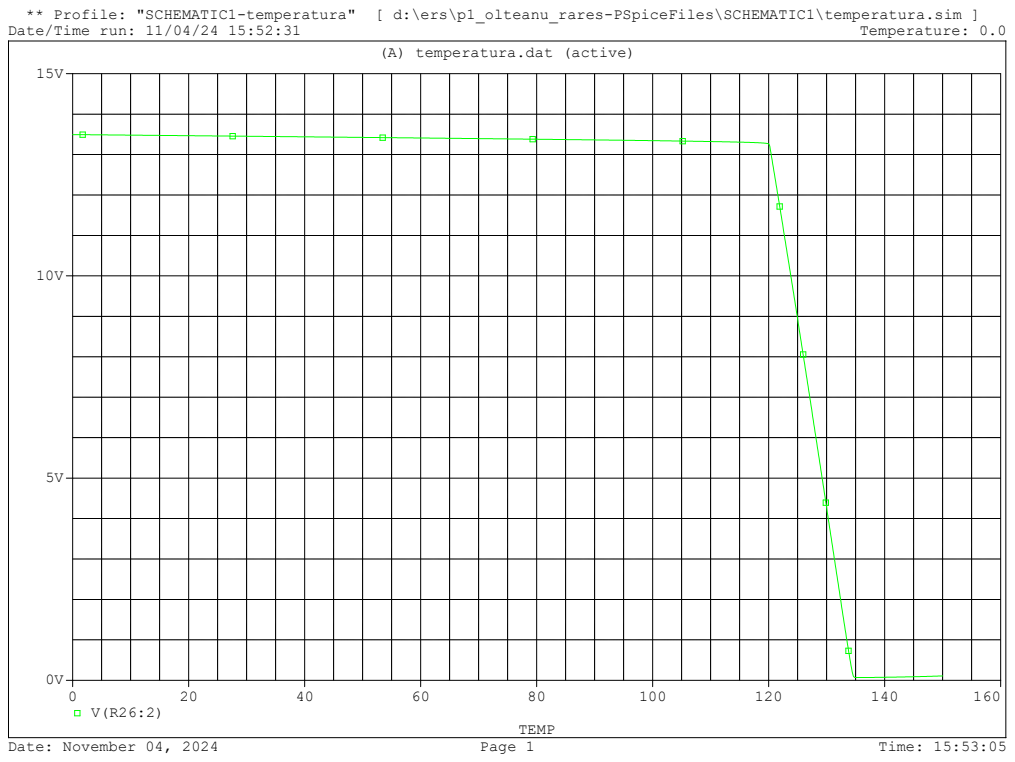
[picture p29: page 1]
Temperature: 0.0; Date: November 04, 2024; Page 1; Time: 15:53:05; TEMP

** Profile: "SCHEMATIC1-temperatura" [ d:\ers\p1_olteanu_rares-PSpiceFiles\SCHEMATIC1\temperatura.sim ]
Date/Time run: 11/04/24 15:52:31

(A) temperatura.dat (active)
